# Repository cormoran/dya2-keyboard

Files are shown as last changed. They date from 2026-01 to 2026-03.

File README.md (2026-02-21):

# <picture><source srcset="docs/public/dya-dark.svg" media="(prefers-color-scheme: dark)"> DYA2 Split Keyboard

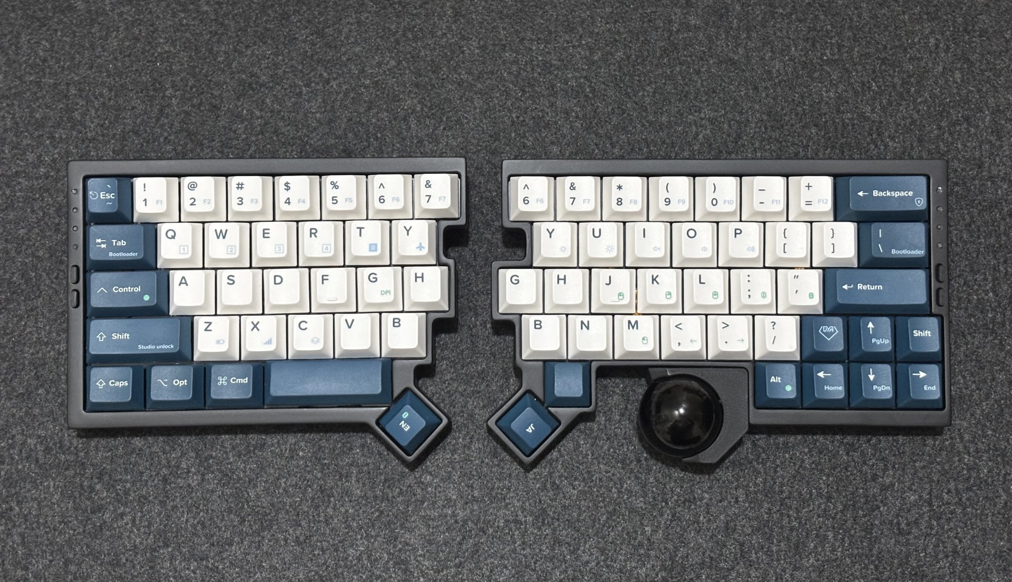
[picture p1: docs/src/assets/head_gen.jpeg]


Hardware designs are under preparation for publish...

## License

- DYA logo <picture><source srcset="docs/public/dya-dark.svg" media="(prefers-color-scheme: dark)">: All rights reserved.
- Other keyboard picture : CC BY
- Hardware
  - kicad library (./hardware/kicad_library/\*) and sch (\*.kicad_sch): MIT
  - PCB (\*.kicad_pcb): **CC BY-NC**
  - Case data (\*.stl): CC BY
- Documents
  - All pictures+ CC BY
  - Other source codes: MIT

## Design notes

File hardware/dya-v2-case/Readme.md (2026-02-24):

# DYA2 Keyboard Case Data

All files are available in [this Google Drive directory](https://drive.google.com/drive/folders/1ZEN23xsCUHo-18NyI8FSiMm8lmljceus?usp=drive_link).

## 2D DXF

3D data was designed based on below 2D DXF. But it can be different from 3D data, since some of the surfaces are edited directly in 3D model.

- [TopCase](https://drive.google.com/file/d/1yOBgUZQl2Zo97JnLZBKS5_XB2pb0bkpV/view?usp=drive_link)
- [BottomCase](https://drive.google.com/file/d/1IbZsgNPL-G4lhiw5IdBfzz8D3HgvFzjm/view?usp=drive_link)
- [TopPlate](https://drive.google.com/file/d/1yOBgUZQl2Zo97JnLZBKS5_XB2pb0bkpV/view?usp=drive_link)

## 3D Data

Link to the latest versions are summarized in below:

- For PLA with insert nut
  - [DYA2 v58.step](https://drive.google.com/file/d/1GUyOGR_NIzhSRBstqwC4YxvJoqwkRAov/view?usp=drive_link)
  - [DYA2-Trackball v4.stl](https://drive.google.com/file/d/1xNEte9bfMDOHjX-XjD9ouIbOX3-cyFVn/view?usp=drive_link)
    - stl because exporting to step file didn't work well :(
  - [XIAO-over v12 x 9.3mf](https://drive.google.com/file/d/1ttBiFGda33AoVqViXmSofXiBs5eIHgoY/view?usp=drive_link)
- For CNC
  - [DYA2 v37 Weight.step](https://drive.google.com/file/d/1O_AQXGu4fa-7VJVzOm7PxX8MRnGYcRql/view?usp=drive_link) - Tested with [JLCCNC](https://jlccnc.com/)

### 3mf for Bambu Studio

Below is an example setup for Bambu Studio for X1C.

- [TopCase and Weight](https://drive.google.com/file/d/1X5pBLtazw2v5_TMJEdkGAeLKjAuC2xHo/view?usp=drive_link)
- [BottomCase](https://drive.google.com/file/d/1tQdBppNNfY6DObMM-RVunVdRlT9PlLCL/view?usp=drive_link)]

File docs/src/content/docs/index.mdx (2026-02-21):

---
title: DYA2
description: 電池で動く、据え置き向け分割型トラックボール付きキーボード
template: splash
hero:
  title: |
    DYA2 Logo
    DYA2 Logo
    DYA2
  tagline: 電池で動く、据え置き向け分割型トラックボール付きキーボード
  image:
    file: ../../assets/head_gen.jpeg
    alt: DYA2 キーボード
  actions:
    - text: ビルドガイド
      link: /dya2-keyboard/build-guide/v1/
      icon: right-arrow
      variant: primary
    - text: 設計データ
      link: https://github.com/cormoran/dya2-keyboard
      icon: github
      variant: secondary
    - text: ビルドキットを購入
      link: https://cormoran707.booth.pm/items/7627440
      icon: information
      variant: minimal
    - text: DYA Studio で設定
      link: https://studio.dya.cormoran.works
      icon: right-arrow
      variant: secondary
---

import { Card, CardGrid } from "@astrojs/starlight/components";

## 特徴

<CardGrid>
<Card title="タッチセンサー搭載">
    キートップに触れると動作するタッチセンサーを搭載左右に４つずつ搭載できます。
    トラックボールのスクロールモード切り替えなどに便利です。
  </Card>
  <Card title="有線にも対応した無線左右分割キーボード">
    自由な手の位置でタイピングできます。

    安定性を重視する場面では、ケーブルを繋ぐだけで自動的に有線接続に切り替わります。

  </Card>
  <Card title="Web から設定を変更できる DYA Studio 対応">
    ファームウェアを書き換えることなく、キーマップの設定やトラックボールの調整、バッテリー履歴の確認がブラウザから行えます。
    <a href="https://studio.dya.cormoran.works">DYA Studio</a> は iOS からも利用できます。

  </Card>
  <Card title="電池駆動" >
    左右はそれぞれ単４電池１本ずつで動作します。

    リチウムポリマーバッテリーと比べて発火の心配が低く、安心して使用できます。

  </Card>
  <Card title="日本語配列にも対応">
    使い慣れた Row Staggered 配列の 60% キーボードです。

    同じハードウェアで英語配列と日本語配列の両方に対応しています。

    DYA Studio も日本語配列向けの表示に対応しています。

  </Card>
  <Card title="34mm トラックボール内蔵">
    マウスを持ち替えることなくカーソル操作が可能です。

    34mmの大きなトラックボールを搭載しているので、快適に操作できます。

  </Card>
  <Card title="自由なカスタマイズ">
    ZMKファームウェアを使っておりソースコードも公開しています。

    キーマップやマクロ、細かな振る舞いを自由にカスタマイズできます。

  </Card>
</CardGrid>

## 写真

## バージョン情報

ハードウェアに新しい機能が追加されたり、後方互換性の無い変更が行われた場合にメジャーバージョンアップします。

- **V1.1** (2026/02) - キーケット前の試作版

## サポート

- **販売・サポート**: [Booth](https://cormoran707.booth.pm)
- **技術情報・ソースコード**: [GitHub](https://github.com/cormoran/dya-dash-keyboard)
- **最新情報**: X [@cormoran707](https://twitter.com/cormoran707)

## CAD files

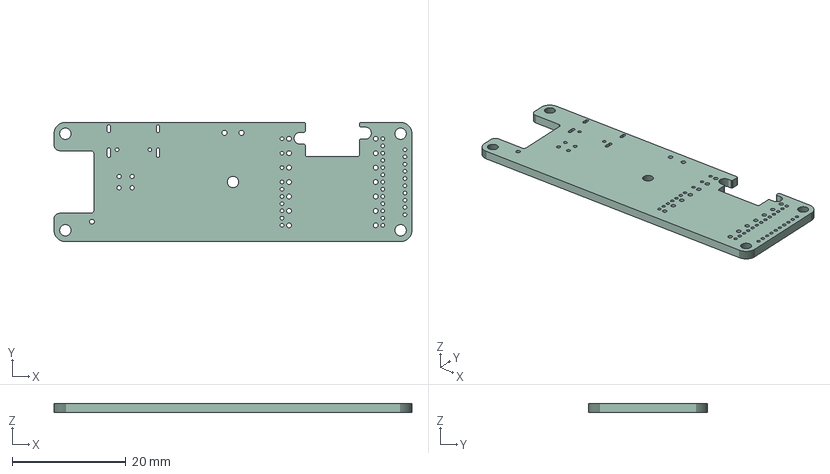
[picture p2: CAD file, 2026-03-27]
hardware/dya-v2/24pin-ffc-expander/mcu-xiao-nrf52840-plus.step
63.0 x 21.0 x 1.60 mm

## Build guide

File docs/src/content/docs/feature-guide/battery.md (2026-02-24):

---
title: バッテリー残量表示
sidebar:
  order: 5
---

電源を入れた際に左右のバッテリー残量が LED に表示されます。

バッテリー残量は、４つの LED x 3 色で 12 段階表示されます。

- ４つの LED: 下から25%ずつに対応
- 色: 残量が多い側から緑 → 黄 → 赤で変化

以下は DYA Dash での説明です。LED の向きが異なりますが基本的な読み方は同じです。

例えば下の図で、左手の緑緑緑は以下のように読みます。

- ４つ目が点灯していないので -25%で 75%以下
- ３つ目が緑なので、50%から 75%の間で残量が多い方（３分割した一番多い区間にある）

右手の緑緑黄状態は以下のように読みます

- ４つ目が点灯していないので -25%で 75%以下
- ３つ目が黄色なので、50%から 75%の間でちょうど真ん中あたり（３分割した真ん中の区間にある）

以下の画像は DYA Dash での例です。DYA2 では LED の向きが変わっていますが色は同じです

TODO: DYA2 で画像と説明を更新

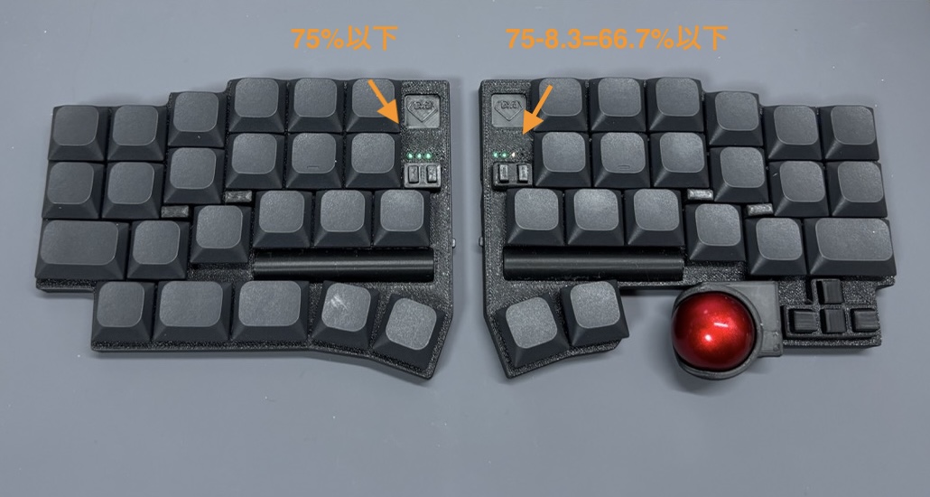
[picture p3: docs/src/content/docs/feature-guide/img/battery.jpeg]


:::note

残量表示はニッケル水素電池の電圧曲線に従って実装していますが、回路による電圧降下もあるため、実態に則しているかはまだあまり詳しく調べられていません。

全然違う気がした場合は教えてください。

:::

## 残量を確認する方法

電源を切らずに残量を確認するためには、 Config(下の赤いキー) + Z を押します。
しばらくの間 LED が電池残量を表示します。

その他、残量が少なくなったら定期的に LED をアラート点灯させる機能もついています。



## 電池持ちの分析

以下の記事で DYA Dash の回路でより詳しい Power profile 結果を解説しています。基本的には DYA2 でも同じような結果になります。

- [XIAO nrf52840 と ZMK を使ったキーボードのスリープ時消費電力](https://note.com/cormoran/n/n72a9d815ed55)
- [XIAO nrf52840 と ZMK を使ったトラックボールキーボード使用時の消費電力](https://note.com/cormoran/n/n7cd3f64d9a13)

## バッテリー残量履歴の確認

DYA Studio からバッテリー残量履歴の確認ができます。

:::tip[2026/02/25現在]
現在機能調整のため、公開しているファームウェアでは一時的に無効化しています。
:::

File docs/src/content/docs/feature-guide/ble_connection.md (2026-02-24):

---
title: 接続先の切り替え
sidebar:
  order: 3
---

接続先は Config レイヤーの `Q` `W` `E` `R` `T` で切り替えることができます。

また、現在の接続先は右手の４つのLEDから確認することができます。

- `Q`~`R`は無線接続0番から3番に対応
- LED は一番上が0番、一番下が３番に対応

### ペアリング/接続

Config レイヤーキー（下の図の赤いキー）を押しながら `Q`~`R` を押すと対応する接続先が選択され、右側の LED が以下のどれかの状態になります

- 黄色に点滅: ペアリング待機状態 PC から BLE 接続できます
- 赤く点滅: ペアリング済みの PC に接続待ち状態
- 青く点灯: 接続完了

### ペアリング解除

ペアリングを解除するためには、Config を押しながら `Q`~`R` を５秒以上押してください。

LED が黄色く点滅しペアリング待機状態に変わります。

### BLE/USB 切り替え

USB, BLE 両方に接続した状態で Config を押しながら以下の `OUT TOG` を押すと BLE/USB どちらが優先されるかが変わります。

USB が優先されている時、BLE接続先以外の３つのLEDが緑色に点灯します。



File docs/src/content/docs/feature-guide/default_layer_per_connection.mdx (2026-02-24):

---
title: 接続先ごとにキーマップを変える
description: DYA2 のデフォルトキーマップの解説
sidebar:
  order: 4
---

Windows PC と Mac や iPad など複数の OS とペアリングしている場合、OS ごとに必要なキーマップが違っていて困ります。

DYA2 には、接続先（BLE1, 2, 3, 4, USB）ごとにデフォルトレイヤーを切り替える機能が実装されています。

:::note

この機能は接続先の PC を識別してるわけではありません。例えば、USB を他の PC に差し替えるような場合は接続先ごとの切り替えはできません。

:::

Config(以下の赤いキー) + `df nxt`（左の設定ボタン上） を押すたびに、現在選択されている接続先のデフォルトレイヤーが 0 → 1 → 2 → 3 → 4 → 0 と切り替わり、レイヤーに対応する LED が点灯します。



### LED の意味

LED は左上から レイヤー0, 1, 2, 3 右上から 4, 5, 6, 7 に対応しています。

それぞれの LED は対応するレイヤーがアクティブなときに点灯します。接続先ごとに切り替えることができるのはレイヤー0~4の5つです。

- レイヤー 1~4 は接続先ごとに切り替えることができるレイヤーで、デフォルトでは以下のようにOSごとに割り当てる想定でキーマップとLEDの色を設定しています。 `df nxt` を押すたびに、LED が以下の順番で切り替わります。
  - 🔵 Layer1: Windows 空色
  - 🔴 Layer2: Mac 赤色
  - ⚪️ Layer3: iOS 白色
  - 🟠 Layer4: Linux オレンジ
- レイヤー0 はベースレイヤーで常にアクティブになるので、左の一つ目の LED は常に点灯します。Layer1~4 のどれも点灯していない状態は、接続先にレイヤー0が割り当てられている状態になります。
- レイヤー7 は Config レイヤーで、左手左下キーを押している間アクティブになるので、右の一番下の LED は赤いキーを押している間常に点灯します。
- レイヤー5,6 はマウスレイヤーで、トラックボール操作中の場合点灯します。

なお、Config + `C` キーで現在アクティブなレイヤーを確認することもできます。
例えば、Config + `C`を押した状態でトラックボールを動かすと右の上から３つ目のLEDが点灯するはずです。

なお、上の1~4のマッピングはあくまでおすすめとして設定してだけなので、レイヤーの使い方は自由です。

以下の動画は姉妹品の DYA Dash で接続先ごとにレイヤーが切り替わる様子を撮影したものです。DYA2 も同様の動作になります。

import { YouTube } from "astro-embed";

<YouTube id="PggxfXZUtnA" posterQuality="high" />

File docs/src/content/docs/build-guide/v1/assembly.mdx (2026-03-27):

---
title: 組み立て
description: 基板とケースを組み立てます
sidebar:
  order: 3
---

import { Image } from "astro:assets";
import { Steps } from "@astrojs/starlight/components";
import topPlateSeparated from "./img/assembly/1_1_top_plate_separated.jpeg";
import circuitBoardSeparated from "./img/assembly/1_2_circuit_board_separated.jpeg";

基板の切り離しから始めて、ケースへの取り付けと動作確認を行います。

:::caution[作業前の注意事項]

- **FFC ケーブル**: 乱雑に扱うと断線します。折り曲げる際は緩やかに行ってください
- **XIAO の取り付け**: コンスルーに無理な力を加えるとコンスルーが破損します
- **タッチセンサー端子**: 乱雑に扱うと断線するかもしれません
  :::

## 1. 基板の切り離し

回路基板とトッププレートを切り離します。ペンチやニッパーなどを使って基板を繋いでいるマウスビット部分を切断してください。
回路基板の方は手で折り曲げるだけで切断できます。トッププレートの薄い部分はそのまま折り曲げると割れる可能性があるので、プレート側をペンチで挟んで支えながら切断することをおすすめします。

バリが出ている場合はヤスリなどで整えます。

<div className="image-row">
  <Image src={topPlateSeparated} alt="トッププレートの切り離し後（左右）" />
  <Image
    src={circuitBoardSeparated}
    alt="回路基板の切り離し後（左右）"

/>

</div>

## 2. ボトムケースの組み立て

import bottomCaseOverview from "./img/assembly/2_bottom_case_overview.jpeg";

以下の部品と FFC ケーブルを用意します。

<div className="image-row">
  <Image src={bottomCaseOverview} alt="ボトムケースと部品一覧" />
  <div>
    <ul>
      <li>ネジパック A</li>
      <li>ボトムケース（左右）</li>
      <li>電池ケース x2</li>
      <li>制御基板 x2</li>
      <li>XIAO 固定用カバー x2</li>
      <li>電源スイッチカバー x2</li>
      <li>リセットボタン x1（右側用）</li>
      <li>XIAO nRF52840 Plus x2（ファームウェア書き込み済み）</li>
    </ul>
  </div>
</div>

### 2.1 電池ケースの取り付け

import batteryCase from "./img/assembly/2_1_battery_case.jpeg";
import batteryCaseScrewed from "./img/assembly/2_1_battery_case_screwed.jpeg";

電池ケースをボトムケースにはめ込み、左右ともに **M2 5mm ねじ（短い方）× 2** でねじ止めします。

M2 5mm ねじに適合するドライバーは１番サイズです。

<div className="image-row">
  <Image src={batteryCase} alt="電池ケースをボトムケースにはめ込む" />
  <Image src={batteryCaseScrewed} alt="電池ケースをねじ止めする" />
</div>

### 2.2 制御基板の組み立て

import xiaoCut from "./img/assembly/xiao_cut.jpeg";
import xiaoBoardAndCover from "./img/assembly/2_2_1_xiao_board_and_cover.jpeg";
import xiaoAttached from "./img/assembly/2_2_1_xiao_attached.jpeg";
import xiaoAttachedBoth from "./img/assembly/2_2_1_xiao_attached_both.jpeg";
import powerSw from "./img/assembly/2_2_2_power_sw.jpeg";
import powerSwSide from "./img/assembly/2_2_2_power_sw_side.jpeg";
import powerSwBoth from "./img/assembly/2_2_2_power_sw_both.jpeg";
import ffcCables from "./img/assembly/2_2_3_ffc_cables.jpeg";
import ffcRight from "./img/assembly/2_2_3_ffc_right.jpeg";
import ffcLeft from "./img/assembly/2_2_3_ffc_left.jpeg";

<Steps>

1. 制御基板を切り離す

   ２つの制御基板が繋がった状態で届いた場合は、基板を切り離します。手で折り曲げるだけで切り離せます。

1. 制御基板の XIAO のリセットスイッチにかぶる部分が切り欠きになっていることを確認する。
   もし画像の状態と違う場合はニッパーなどで出っ張りを切断し、以下の画像のようにしてください。これをしないと右側をボトムケースに取り付けるときにリセットスイッチが高確率で破損します。

   <div className="image-row">
     <Image src={xiaoCut} alt="制御基板の切り欠き" />
   </div>

1. **XIAO をコンスルーにはめ込む**

   XIAO の裏側が見えるように、USB コネクタが下側になる向きで制御基板のコンスルーの間にはめ込みます。

   コンスルーのピンは XIAO のピンの切り欠き部分に入るようになっています。

   <div className="image-row">
     <Image src={xiaoBoardAndCover} alt="制御基板とカバー" />
   </div>

1. **カバーを取り付ける**

   コンスルーのピンがカバーのスリットにピッタリと入っていることを確認しながら押し込みます。ずれたまま無理に押し込むとコンスルーが破損するので注意してください。
   この時点では押し込んでも浮き上がってきますが、問題ありません。次のステップでねじ止めして固定します。

   <div className="image-row">
     <Image src={xiaoAttached} alt="XIAO の取り付け" />
   </div>

1. **左右両方にカバーを取り付ける**

   <div className="image-row">
     <Image src={xiaoAttachedBoth} alt="左右のカバー取り付け完了" />
   </div>

1. **電源スイッチカバーを取り付ける**

   スイッチカバーには向きがあります。内部の切り欠きが片側に寄っているので、スペースが大きい方が基板側になるように取り付けてください。

   なお、スイッチカバーは強度と見た目でトレードオフがあるため、3Dプリントの印刷方向が異なる２種類が同梱されている場合があります。その場合はお好きな方をお使いください。もし取り付け時に破損した場合はもう一方をお使いください。

   <div className="image-row">
     <Image src={powerSw} alt="電源スイッチカバー（正面）" />
     <Image src={powerSwSide} alt="電源スイッチカバー（側面・向き確認）" />
   </div>

1. **左右両方に電源スイッチカバーを取り付ける**

   <div className="image-row">
     <Image src={powerSwBoth} alt="電源スイッチカバー左右取り付け完了" />
   </div>

1. **制御基板に FFC ケーブルを接続する**
   - **左側の基板**: 24pin のみ接続
   - **右側の基板**: 24pin と 6pin の両方を接続

   接続方法：コネクタの黒いロックを縦にして、FFC ケーブルの金属端子が基板側に来るように差し込み、ロックを横に倒して固定します。

   ２枚目の写真はロック解除の状態で、３枚目の写真はロックした状態です。

   <div className="image-row">
     <Image src={ffcCables} alt="FFC ケーブルの接続方法" />
     <Image src={ffcLeft} alt="左側：24pin のみ接続 ロック前" />
     <Image src={ffcRight} alt="右側：24pin + 6pin 接続　ロック後" />
   </div>

</Steps>

### 2.3 制御基板のボトムケースへの取り付け（右）

import resetButton from "./img/assembly/2_2_4_reset_button.jpeg";
import resetButtonAttaching from "./img/assembly/2_2_4_reset_attaching.jpeg";
import resetButtonAttached from "./img/assembly/2_2_4_reset_attached.jpeg";
import mountRightBattery from "./img/assembly/2_2_5_mount_right_battery.jpeg";
import mountRight from "./img/assembly/2_2_5_mount_right.jpeg";
import mountRightScrew from "./img/assembly/2_2_5_mount_right_screw.jpeg";
import mountRightScrew2 from "./img/assembly/2_2_5_mount_right_screw2.jpeg";

<Steps>

1.  **リセットボタンを取り付ける**

    右側のボトムケースに、太い側をボトムケースに差し込むようにリセットボタンを取り付けます。

    :::caution
    右のリセットボタンは現在試験的な機能扱いです。ボタンが非常に小さいため折れやすいです。

    ファームウェアの書き込みは専用のキーマップ(`&bootloader`)を使用することでリセットボタンなしでも行えるようになっています。
    :::

    <div className="image-row">
      <Image src={resetButton} alt="リセットボタン（取り付け前）" />
      <Image src={resetButtonAttaching} alt="リセットボタン（取り付け中）" />
      <Image src={resetButtonAttached} alt="リセットボタン（取り付け後）" />
    </div>

2.  **電池ケーブルを接続する**

    右側の制御基板に、電池ケースのケーブルを接続します。

    <div className="image-row">
      <Image src={mountRightBattery} alt="電池ケーブルの接続" />
    </div>

3.  **制御基板をボトムケースに入れる**

    USB 端子と電源スイッチが引っかからないよう、少し斜めから入れてください。力を入れなくても入るようになっています。

    :::caution
    無理に押し込むと電源スイッチやリセットボタンが破損します。
    :::

    <div className="image-row">
      <Image src={mountRight} alt="右側制御基板の挿入" />
    </div>

4.  **XIAO カバー部分をねじ止めする（長い方）**

    **M2 8mm ねじ（長い方）× 3** でねじ止めします。

    強く締めるとリセットボタンが押された状態になってしまう可能性があるので調整してください。

    <div className="image-row">
      <Image src={mountRightScrew} alt="右側 XIAO カバー部のねじ止め" />
    </div>

5.  **残りの穴をねじ止めする（短い方）**

    **M2 5mm ねじ（短い方）× 2** でねじ止めします。

    <div className="image-row">
      <Image src={mountRightScrew2} alt="右側基板の残りのねじ止め" />
    </div>

</Steps>

### 2.4 制御基板のボトムケースへの取り付け（左）

import mountLeft from "./img/assembly/2_2_6_mount_left.jpeg";
import mountLeftBattery from "./img/assembly/2_2_6_mount_left_battery.jpeg";
import mountingLeft from "./img/assembly/2_2_6_mounting_left.jpeg";
import mountingLeft2 from "./img/assembly/2_2_6_mounting_left2.jpeg";
import mountLeftScrew from "./img/assembly/2_2_6_mount_left_screw.jpeg";
import mountLeftScrew2 from "./img/assembly/2_2_6_mount_left_screw2.jpeg";
import mountLeftScrew3 from "./img/assembly/2_2_6_mount_left_screw3.jpeg";

:::note
左側の制御基板は、右側とは裏表が逆になります。
:::

<Steps>

1.  **電池ケーブルを接続する**

    左側の制御基板に、電池ケースのケーブルを接続します。

    <div className="image-row">
      <Image src={mountLeft} alt="左側制御基板（裏表確認）" />
      <Image src={mountLeftBattery} alt="電池ケーブルの接続" />
    </div>

2.  **制御基板をボトムケースに入れる**

    USB 端子と電源スイッチが引っかからないよう、少し斜めから入れてください。左側は右よりも余裕が少なくなっています。基板が押し返してきて入れづらいですが、注意深く入れてください。

    :::caution
    無理に押し込むと電源スイッチのノブ部分が折れるため注意深く入れてください。

    また、コンスルーのバネで基板が押し返されてくるので指で押さえたまま次のステップに進んでください。
    :::

    <div className="image-row">
      <Image src={mountingLeft} alt="左側制御基板の挿入（途中）" />
      <Image src={mountingLeft2} alt="左側制御基板の挿入（完了）" />
    </div>

3.  **中央の穴をねじ止めする（最初に止める）**

    **M2 8mm ねじ（長い方）× 1** にナイロンワッシャーを取り付けて**中央の穴をねじ止め**します。強く締めすぎるとケース裏側に盛り上がりができるので、しっかり固定しつつも締めすぎに注意してください。

    <div className="image-row">
      <Image src={mountLeftScrew} alt="左側中央穴のねじ止め" />
    </div>

4.  **XIAO カバー部分の残りをねじ止めする**

    **M2 8mm ねじ（長い方）× 2** とナイロンワッシャーでねじ止めします。

    <div className="image-row">
      <Image src={mountLeftScrew2} alt="左側 XIAO カバー部のねじ止め" />
    </div>

5.  **残りの穴をねじ止めする（短い方）**

    **M2 5mm ねじ（短い方）× 2** でねじ止めします。

    <div className="image-row">
      <Image src={mountLeftScrew3} alt="左側基板の残りのねじ止め" />
    </div>

</Steps>

## 3. エンブレムプレートの取り付け

import emblemPlateParts from "./img/assembly/3_emblem_plate.jpeg";
import emblemPlateAttached from "./img/assembly/3_emblem_plate_attached.jpeg";
import emblemPlateBottom1 from "./img/assembly/3_emblem_plate_bottom1.jpeg";
import emblemPlateBottom2 from "./img/assembly/3_emblem_plate_bottom2.jpeg";
import emblemPlateBottom3 from "./img/assembly/3_emblem_plate_bottom3.jpeg";

ネジパック B、ボトムエンブレム x2、ボトムケースを用意します。
画像では右側に特注の真鍮製プレートを使用しています（詳細は[追加のカスタマイズ](/dya2-keyboard/build-guide/v1/extension)を参照）。

<div className="image-row">
  <Image src={emblemPlateParts} alt="エンブレムプレートの取り付け部品" />
</div>

エンブレムプレートをはめ込み、**M2 4mm ねじ（黒色）× 4** でねじ止めします。ねじが短いのでねじ穴が潰れやすいです。ガタつかない程度に固定できれば問題ありません。締めすぎに注意してください。

M2 4mm ねじに適合するドライバーは０番サイズです。

<div className="image-row">
  <Image src={emblemPlateAttached} alt="エンブレムプレート取り付け後" />
</div>

取り付け後のボトムケースはこのような状態になります。

<div className="image-row">
  <Image src={emblemPlateBottom1} alt="エンブレムプレート取り付け後の底面" />
</div>

参考：JLCPCB で真鍮プレートを鏡面加工したものと通常仕上げの比較です。

<div className="image-row">
  <Image
    src={emblemPlateBottom2}
    alt="真鍮プレート（鏡面加工あり）"/>

<Image src={emblemPlateBottom3} alt="真鍮プレート（通常仕上げ）" />

</div>

## 4. トラックボール基板の取り付け

import trackballParts from "./img/assembly/4_trackball_parts.jpeg";
import trackballLens from "./img/assembly/4_trackball_lens.jpeg";
import trackballLens2 from "./img/assembly/4_trackball_lens2.jpeg";
import trackballFfc from "./img/assembly/4_trackball_ffc.jpeg";
import trackballCase from "./img/assembly/4_trackball_case.jpeg";
import trackballCase2 from "./img/assembly/4_trackball_case2.jpeg";
import trackballCase3 from "./img/assembly/4_trackball_case3.jpeg";
import trackballCase4 from "./img/assembly/4_trackball_case4.jpeg";
import trackballMounted from "./img/assembly/4_trackball_mounted.jpeg";
import trackballScrew from "./img/assembly/4_trackball_screw.jpeg";
import trackballScrew2 from "./img/assembly/4_trackball_screw2.jpeg";
import trackballFinal from "./img/assembly/4_trackball_final.jpeg";

ネジパック B の残りと以下の部品を用意します。

<div className="image-row">
  <Image src={trackballParts} alt="トラックボール関連部品" />
</div>

<Steps>

1.  **保護シートを剥がす**

    トラックボールセンサーについている茶色の保護シートを剥がします。剥がすとセンサーの穴が露出します（上の画像は剥がした状態）。

2.  **レンズを取り付ける**

    レンズの突起がセンサーの穴に入るように取り付けます。突起は裏側に突き出ます。はんだごてがある場合は突起部分に熱を加えて溶かして固定します。ニッパーで切断するだけでも問題ありません。

    <div className="image-row">
      <Image src={trackballLens} alt="レンズの取り付け（前）" />
      <Image src={trackballLens2} alt="レンズの取り付け（後）" />
    </div>

3.  **6pin FFC ケーブルをセンサー基板に接続する**

    コネクタの黒いロックを縦にして、FFC ケーブルの金属端子が基板側に来るようにして差し込み、ロックを横に倒して固定します。

    <div className="image-row">
      <Image src={trackballFfc} alt="トラックボールセンサーへの FFC 接続" />
    </div>

4.  **センサー基板をトラックボールケースに収める**

    FFC ケーブルをうまく折り曲げて端子に負荷がかからないように差し込みます。FFC ケーブルを強く曲げると断線するので注意してください。

    <div className="image-row">
      <Image src={trackballCase} alt="センサー基板の挿入（途中 1）" />
      <Image src={trackballCase2} alt="センサー基板の挿入（途中 2）" />
      <Image src={trackballCase3} alt="センサー基板の挿入（途中 3）" />
    </div>

5.  **カバーを取り付ける**

    奥まで差し込んだらカバーを取り付けます。

    <div className="image-row">
      <Image src={trackballCase4} alt="トラックボールケースのカバー取り付け" />
    </div>

6.  **ボトムケースに乗せて裏返す**

    <div className="image-row">
      <Image src={trackballMounted} alt="トラックボールをボトムケースに設置" />
    </div>

7.  **ねじ止めする**

    **M2 4mm ねじ（黒色）× 3** で軽くねじ止めします。後でトラックボール位置を調整できるので、この時点では軽く止める程度で大丈夫です。

    <div className="image-row">
      <Image src={trackballScrew} alt="トラックボールのねじ止め" />
      <Image src={trackballScrew2} alt="トラックボールのねじ止め（別角度）" />
    </div>

8.  **FFC ケーブルの位置を調整する**

    <div className="image-row">
      <Image src={trackballFinal} alt="FFC ケーブル位置調整後" />
    </div>

</Steps>

## 5. キースイッチ基板の組み立て

import keyswitchOverview from "./img/assembly/5_keyswitch.jpeg";
import keyswitchTadpole from "./img/assembly/5_1_tadpole1.jpeg";
import keyswitchTadpole2 from "./img/assembly/5_1_tadpole2.jpeg";
import keyswitchSettingSwitch from "./img/assembly/5_2_setting_switch.jpeg";
import keyswitchSettingSwitch2 from "./img/assembly/5_2_setting_switch2.jpeg";
import keyswitchSettingSwitchBoth from "./img/assembly/5_2_setting_switch_both.jpeg";
import keyswitchStabilizer from "./img/assembly/5_3_stabilizer_en.jpeg";
import keyswitchPre from "./img/assembly/5_4_keyswitch_pre.jpeg";
import keyswitchPre2 from "./img/assembly/5_4_keyswitch_pre2.jpeg";
import keyswitchPreBoth from "./img/assembly/5_4_keyswitch_pre_both.jpeg";
import touchSensor from "./img/assembly/5_5_touch_sensor.jpeg";
import touchSensorTape from "./img/assembly/5_5_touch_sensor_tape.jpeg";
import touchSensorTape2 from "./img/assembly/5_5_touch_sensor_tape2.jpeg";
import touchSensorScrew from "./img/assembly/5_5_touch_sensor_screw.jpeg";
import touchSensorAll from "./img/assembly/5_5_touch_sensor_all.jpeg";
import keyswitchClick from "./img/assembly/5_6_keyswitch_click.jpeg";
import keyswitchClick2 from "./img/assembly/5_6_keyswitch_click2.jpeg";
import keyswitchLeft from "./img/assembly/5_6_keyswitch_left1.jpeg";
import keyswitchLeft2 from "./img/assembly/5_6_keyswitch_left2.jpeg";
import keyswitchTouchSensor from "./img/assembly/5_6_keyswitch_touchsensor.jpeg";
import keyswitchTouchSensor2 from "./img/assembly/5_6_keyswitch_touchsensor2.jpeg";
import keyswitchFinal from "./img/assembly/5_final.jpeg";

以下の部品を用意します。

<div className="image-row">
  <Image src={keyswitchOverview} alt="キースイッチ基板組み立ての部品一覧" />
  <div>
    <ul>
      <li>スタビライザー</li>
      <li>キースイッチ</li>
      <li>Tadpole ピン</li>
      <li>設定スイッチ x4（左右２つずつ）</li>
      <li>ねじパック C</li>
      <li>タッチセンサー</li>
      <li>トッププレート</li>
      <li>キースイッチ基板</li>
    </ul>
  </div>
</div>

### 5.1 Tadpole ピンの取り付け

Tadpole ピンをトッププレートの裏側から差し込みます。

<div className="image-row">
  <Image src={keyswitchTadpole} alt="Tadpole ピンの取り付け（右側）" />
  <Image src={keyswitchTadpole2} alt="Tadpole ピンの取り付け（左側・裏返し）" />
</div>

### 5.2 設定スイッチの取り付け

設定スイッチを左右２つずつキースイッチ基板に差し込みます。はんだ付けしない場合はピンのバネの力で導通します。はんだごてをお持ちの場合ははんだ付けを推奨します。

<div className="image-row">
  <Image src={keyswitchSettingSwitch} alt="設定スイッチの取り付け" />
  <Image src={keyswitchSettingSwitch2} alt="設定スイッチの取り付け（別角度）" />
  <Image src={keyswitchSettingSwitchBoth} alt="設定スイッチ左右取り付け完了" />
</div>

### 5.3 スタビライザーの取り付け

キースイッチ基板にスタビライザーを取り付けます。

- **英語配列**の配置は下の画像のとおりです
- **日本語配列**の場合：右上と左内側のスタビライザーは不要、右中央のスタビライザーはエンターキーに合わせた縦向きに変更してください

スタビライザーにルブを塗る場合は取り付ける前に塗ってください。

<div className="image-row">
  <Image src={keyswitchStabilizer} alt="スタビライザーの取り付け（英語配列）" />
  <div style="align-self: center; text-align: center;">
    日本語配列の写真: 準備中
  </div>
</div>

### 5.4 キースイッチの仮止め

トッププレートの４隅にキースイッチをはめ込み、キースイッチ基板に差し込みます。

:::caution
次の手順でタッチセンサーを取り付けるため、**親指エリアのキースイッチは今はまだ取り付けないでください**

下の画像の左では誤って取り付けてしまっています。一つ上か左の場所に取り付けてください。
:::

<div className="image-row">
  <Image src={keyswitchPre} alt="キースイッチの仮止め（片側）" />
  <Image src={keyswitchPre2} alt="キースイッチの仮止め（別角度）" />
  <Image src={keyswitchPreBoth} alt="キースイッチの仮止め（左右）" />
</div>

### 5.5 タッチセンサーの取り付け（スキップ可）

タッチセンサーはキーキャップの裏側に貼り付けて、回路基板にねじ止めします。**端子は繊細なので丁寧に扱ってください**。
対応しているキーは以下の画像+`V`です（**`F` と `V` はどちらか片方のみ**）。

タッチセンサーは後から取り付けすることも可能です。最大８つ設置できますが、まずは使い道が明確なキーだけ取り付けることをおすすめします。
`'` はトラックボールをスクロールモードに切り替えるのにおすすめです。

<div className="image-row">
  <Image src={touchSensor} alt="タッチセンサー対応キーの位置" />
</div>

<Steps>

1.  **タッチセンサーをキーキャップに貼り付ける**

    両面テープを画像のように貼り付けて４辺を折り曲げ、キーキャップ内側に貼り付けます。表裏はどちらでも良いですが、金属面をキーキャップ側（指に近い側）にすると良いかもしれません。ねじ止め部分がキーキャップの上側に来る向きにしてください。

    <div className="image-row">
      <Image src={touchSensorTape} alt="タッチセンサーへの両面テープ貼り付け" />
      <Image
        src={touchSensorTape2}
        alt="タッチセンサーをキーキャップに貼り付け"
      />
    </div>

2.  **タッチセンサーをねじ止めする**

    ネジパック C の **M2 3mm ねじ × 1（センサーごと）** でねじ止めします。導通するようにしっかりとねじ止めしてください。

    <div className="image-row">
      <Image src={touchSensorScrew} alt="タッチセンサーのねじ止め" />
      <Image src={touchSensorAll} alt="タッチセンサー全体の取り付け完了" />
    </div>

</Steps>

### 5.6 残りのキースイッチとキーキャップの取り付け

残りすべてのキースイッチとキーキャップを取り付けます。

<div className="image-row">
  <Image src={keyswitchLeft} alt="キースイッチ取り付け（左側途中）" />
  <Image src={keyswitchFinal} alt="キースイッチ全て取り付け完了" />
</div>

タッチセンサー付きのキーキャップは、接続部がスイッチの上側に挟み込まれるようになります。

<div className="image-row">
  <Image
    src={keyswitchTouchSensor}
    alt="タッチセンサー付きキーキャップの取り付け"
  />
  <Image
    src={keyswitchTouchSensor2}
    alt="タッチセンサー付きキーキャップの取り付け（別角度）"
  />
  <Image
    src={keyswitchLeft2}
    alt="タッチセンサー付きキーキャップをスイッチに装着"
  />
</div>

マウスの左クリックとして使うキー（`M` が推奨）にはタクタイルスピードスイッチがおすすめです。

<div className="image-row">
  <Image src={keyswitchClick} alt="左クリック用スイッチの取り付け" />
  <Image src={keyswitchClick2} alt="左クリック用スイッチの取り付け（別角度）" />
</div>

## 6. トップケースの組み立て

import topCaseOverview from "./img/assembly/6_topcase.jpeg";
import topCaseLeftSettingSwitch from "./img/assembly/6_1_left_setting_switch.jpeg";
import topCaseLeftCircuit from "./img/assembly/6_1_left_circuit.jpeg";
import topCaseLeftCircuit2 from "./img/assembly/6_1_left_circuit2.jpeg";
import topCaseLeftFfc from "./img/assembly/6_1_left_ffc.jpeg";
import topCaseLeftFfc2 from "./img/assembly/6_1_left_ffc2.jpeg";
import topCaseLeftMerge from "./img/assembly/6_1_left_merge.jpeg";
import topCaseRightCircuit from "./img/assembly/6_2_right_circuit.jpeg";
import topCaseRightFfc from "./img/assembly/6_2_right_ffc.jpeg";
import topCaseRightMerge from "./img/assembly/6_2_right_merge.jpeg";
import topCaseScrew from "./img/assembly/6_3_screw.jpeg";
import topCaseScrew2 from "./img/assembly/6_3_screw2.jpeg";
import bottomPad from "./img/assembly/6_4_pad.jpeg";
import batteryCover from "./img/assembly/6_5_battery_cover.jpeg";
import batteryCover2 from "./img/assembly/6_5_battery_cover2.jpeg";
import batteryCover3 from "./img/assembly/6_5_battery_cover3.jpeg";

ネジパック B の残り、ゴム足、ボトムケースと以下の部品を用意します。

<div className="image-row">
  <Image src={topCaseOverview} alt="トップケース組み立ての部品一覧" />
</div>

### 6.1 左側のトップケースの組み立て

<Steps>

1.  **設定スイッチを取り付ける**

    左側のトップケースを裏返して設定スイッチを取り付けます。出っ張りが内側になるようにしてください（正しい向きにしか入りません）。

    <div className="image-row">
      <Image
        src={topCaseLeftSettingSwitch}
        alt="左側トップケースに設定スイッチを取り付け"
      />
    </div>

2.  **回路基板を入れる**

    真っ直ぐ入れると LED 部分が干渉するので、少し斜めから入れてください。

    <div className="image-row">
      <Image src={topCaseLeftCircuit} alt="左側トップケースへの回路基板挿入" />
    </div>

3.  **Tadpole ピンをはめ込む**

    Tadpole ピンをトップケースの穴にしっかりと合わせて奥まで押し込みます。

    <div className="image-row">
      <Image
        src={topCaseLeftCircuit2}
        alt="Tadpole ピンをトップケース穴にはめ込む"
      />
    </div>

4.  **FFC ケーブルを接続する**

    ボトムケースから出ている 24pin FFC ケーブルをトップケースの回路基板に接続します。上下を合わせた状態をイメージして、ケーブルを緩やかに折り曲げて接続してください。**FFC ケーブルは強く曲げると断線します。一度曲げたら戻さないようにしてください。**

    FFC ケーブルは青い樹脂部分が見える側を上に、金属端子が基板側に来るように差し込み、ロックを横に倒して固定します。

    <div className="image-row">
      <Image src={topCaseLeftFfc} alt="左側 FFC ケーブルの折り曲げ方向" />
      <Image src={topCaseLeftFfc2} alt="左側 FFC ケーブルの接続完了" />
    </div>

5.  **ボトムケースと合体させる**

    FFC ケーブルがうまく収まるように調整しながら、トップケースの回路基板をボトムケースの基板に重ねます。Tadpole ピンが外れやすいので、下の画像のように上下逆の状態で取り付けると安定します。

    <div className="image-row">
      <Image
        src={topCaseLeftMerge}
        alt="左側トップケースとボトムケースの合体"
      />
    </div>

</Steps>

### 6.2 右側のトップケースの組み立て

<Steps>

1.  **設定スイッチを取り付ける**

    右側のトップケースを裏返して、設定スイッチを取り付けます。

2.  **回路基板を入れる**

    こちらも LED 部分が干渉するので少し斜めから入れます。入れたら Tadpole ピンをトップケースの穴にしっかりと合わせて奥まで押し込みます。

    <div className="image-row">
      <Image src={topCaseRightCircuit} alt="右側トップケースへの回路基板挿入" />
    </div>

3.  **FFC ケーブルを接続する**

    ボトムケースから出ている 24pin FFC ケーブルを接続します。右側はボトムケースの基板が左とは逆向きになっているため、FFC ケーブルも左側とは逆向きになっており、折り曲げ方を変える必要があります。以下の写真を参考にしてください。**一度曲げたら戻さないようにしてください。**

    <div className="image-row">
      <Image src={topCaseRightFfc} alt="右側 FFC ケーブルの接続" />
    </div>

4.  **ボトムケースと合体させる**

    FFC ケーブルがうまく収まるように調整しながら重ねてください。

    <div className="image-row">
      <Image
        src={topCaseRightMerge}
        alt="右側トップケースとボトムケースの合体"
      />
    </div>

</Steps>

### 6.3 動作確認

ねじ止めする前に動作を確認します。

:::danger
PCとの接続は左右外側のUSB端子を使用してください。左右内側のUSB端子は左右の基板を接続するためのもので、PCとの接続には使用できません。PCが故障する可能性があります。

また、左右をUSB接続した状態で左右両方をPCと接続しないでください。USB電源の逆流対策がされていないため、PCやPCのUSB端子が故障する可能性があります。
:::

<Steps>

1. 有線接続での確認

   右の外側のUSB 端子をPCと接続、左右の内側のUSB端子を互いに接続して、キー入力とトラックボールの動作を確認します。

   なお、左の外側のUSB 端子はファームウェア書き込みのためだけに使用されます。左をPCと接続してもキーボードとしては動作しません。

1. 左右無線での確認（組み立て後でもOK）

   左右の内側のUSB端子を外して左に電池を入れます。左の電源をオン（スイッチを内側にスライド）にして、キー入力とトラックボールの動作を確認します。

1. すべて無線での確認（組み立て後でもOK）

   右側にも電池を入れて、右の電源もオンにします（スイッチを内側にスライド）。

   右のLEDが黄色に点滅している状態でPCやスマートフォンとペアリングしてください。ペアリング方法の詳細は[使い方ガイド](/dya2-keyboard/usage-guide)にも記載しています。

1. すべてのキーが安定して入力できること、トラックボールが正常に動作することを確認してください。

</Steps>

もし左右で逆のファームウェアを書き込んでしまっていた場合は再度正しいファームウェアを書き込んでください。

右側はケース裏のリセットボタンを素早く２回押すと書き込みモードに入ります。

左側は上下のケースを開けて、爪楊枝の腹（尖っていない方）など突起のあるものでリセットボタンを押す必要があります。

:::tip[一部のキーが反応しない/反応が悪い場合]
以下のような点を確認してみてください。もしキーソケットと基板のはんだが外れている場合は、はんだ付けをしていただけると非常にありがたいです。
難しい場合は購入されたプラットフォームのメッセージ機能でご相談ください。

- キースイッチのピンが曲がらずしっかりソケットに差し込まれているか
- キーソケットと基板のはんだが外れてソケットが浮いていないか
- FFC ケーブルが真っ直ぐに差し込まれてソケットがロックされているか
- XIAO の端子とコンスルール基板の接点がしっかり接触しているか
  :::

### 6.4 トップケースとボトムケースのねじ止め

下側5箇所は **M2 8mm ねじ（長い方）**、上側4箇所は **M2 5mm ねじ（短い方）** でねじ止めします。

<div className="image-row">
  <Image src={topCaseScrew} alt="ねじ止め位置（下側）" />
  <Image src={topCaseScrew2} alt="ねじ止め位置（上側）" />
</div>

### 6.5 ゴム足の取り付け

裏側の８箇所にゴム足を貼り付けます。

<div className="image-row">
  <Image src={bottomPad} alt="底面のゴム足の取り付け位置" />
</div>

### 6.6 電池カバーの取り付け

電池カバーは裏側から差し込むように取り付けます。カバーは最初は少し硬いですが、何度か取り付けるうちに柔らかくなってきます。

カバーは取り付けるとロックされたような状態になっており、カバーの上部を押さえながら指の腹で少しスライドすると外れる設計になっています。爪を使って無理に引っ張ると爪が割れる可能性があるのでご注意ください。

<div className="image-row">
  <Image src={batteryCover} alt="電池カバーの取り付け（差し込み）" />
  <Image src={batteryCover2} alt="電池カバーの取り付け（ロック）" />
  <Image src={batteryCover3} alt="電池カバーの取り付け完了" />
</div>

## 完成！

import topCaseFinal from "./img/assembly/6_final.jpeg";

<div className="image-row">
  <Image src={topCaseFinal} alt="DYA2 完成！" />
</div>

お疲れさまでした！続いて使い方ガイドをご覧ください。

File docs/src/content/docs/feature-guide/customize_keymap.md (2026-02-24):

---
title: キーマップのカスタマイズ
description: DYA2 のキーマップカスタマイズ方法の解説
sidebar:
  order: 2
---

DYA2 のキーマップを変更する方法を解説したページです。
自由度と難易度の違う３つの方法があります。

1. **DYA Studio**: 最も簡単にさまざまな設定ができます。一部複雑なカスタマイズはできませんが今後機能を追加予定です。
   - **ZMK Studio**: ZMK 公式のキーマップカスタマイズツールです。最新機能が使える可能性がありますが、基本的には DYA Studio で同等以上の機能が提供されています。
2. **keymap editor**: Github レポジトリを作る必要がありますが、プログラミングなしで ZMK Studio よりも複雑なカスタマイズができます。
3. **プログラミング**: プログラミングの知識が必要ですが自由自在にカスタマイズができます。

## 1. DYA Studio を使ったカスタマイズ

ZMK Studio と同等のキーマッピング変更に加えて、トラックボールの調整などがファームウェア書き換えなしに行えます。

https://studio.dya.cormoran.works/ からアクセスできます。

### USB 接続でアクセスする方法

WebSerial に対応したブラウザで利用できます。モバイルOSでは利用できません。

1. PC とキーボード右手の外側の USB ポートを接続
2. https://studio.dya.cormoran.works/ にアクセスして USB マークの接続ボタンを選択
3. DYA2 を選択して接続
4. Fn+Caps (Fn:右下の一つ上, Caps: 左下)で `&studio unlock` を実行

※2024/02/24 現在一部の機能は左右を有線接続した状態では正常に動作しません。左右は無線接続にした状態でご利用ください。必要な実装していないだけなので今後対応予定です。

### 無線接続でアクセスする方法

Web Bluetooth に対応したブラウザで利用できます。iOS の場合は Bluefy というブラウザアプリから接続できます。Android は未検証です。

1. キーボードの USB ケーブルを外すか、無線接続優先モードに変更
2. Fn+Caps (Fn:右下の一つ上, Caps: 左下)で `&studio unlock` を実行
   - これを先にやらないと次のステップでデバイスが見つかりません
3. https://studio.dya.cormoran.works/ にアクセスして BLE マークの接続ボタンを選択
4. DYA2 を選択して接続
   - iOS の場合は現在周りにあるすべての BLE デバイスが表示されます。たくさんの無線機器に囲まれて暮らしている方はがんばって DYA2 を探してください。（今後できれば改善予定）

### 参考: ZMK Studio を使ったカスタマイズ

基本的には DYA Studio と同じように利用できます。以下の２種類の方法があります。

- ブラウザ上で動く公式サイト https://zmk.studio/ (USB 接続時のみ対応)
- PC アプリ https://zmk.studio/download (無線接続時も対応)

## 2. keymap editor を使ったカスタマイズ

ファームウェアのソースコードを自動で書き換えてくれるノーコードツール https://nickcoutsos.github.io/keymap-editor/ を使ったカスタマイズ方法です。
ZMK Studio ではできないマクロなどの高度なカスタマイズができます。

:::note[注意]
以下の内容は DYA2 のレポジトリではまだ検証できていません。
:::

### 設定レポジトリを Github に準備する

1. https://github.com/ のアカウントを作ります。
2. https://github.com/cormoran/zmk-keyboard-dya2 をテンプレートとして設定レポジトリを作ります。
   以下の画像は DYA Dash の使い回しです。

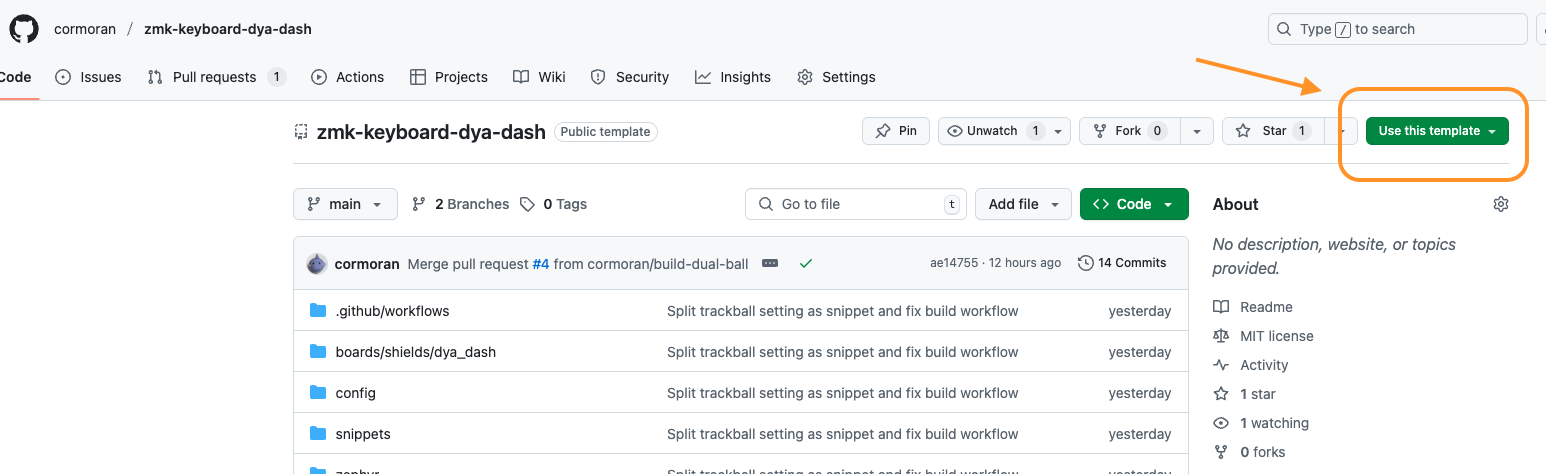
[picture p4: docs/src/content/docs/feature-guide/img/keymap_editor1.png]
   

3. 自動的にファームウェアのビルドが始まることを確認します。
   - 作成されたレポジトリの "Actions" タブをクリックすると "Initial commit" という workflow が動いていると思います。
   - ビルドが終わるとその workflow の Summary ページの Artifacts に zip 圧縮されたファームウェア一式をダウンロードできるリンクが出現します。

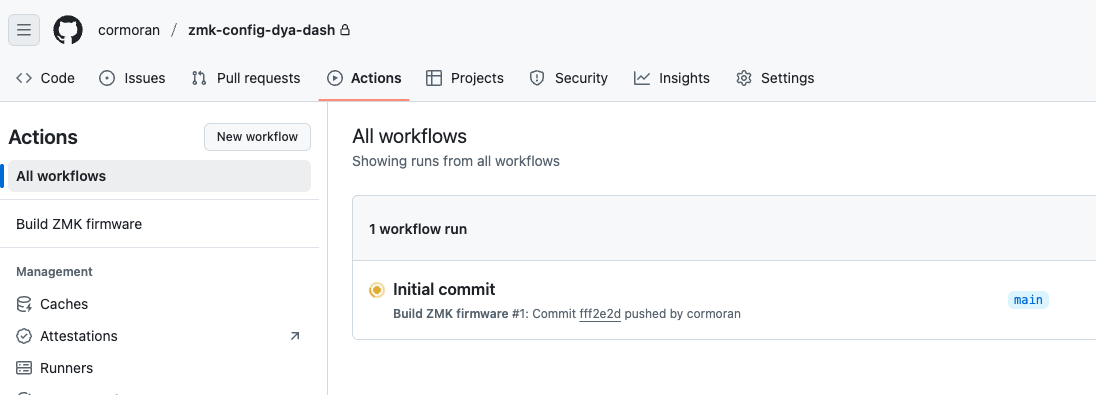
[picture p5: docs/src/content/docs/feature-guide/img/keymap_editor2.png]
   
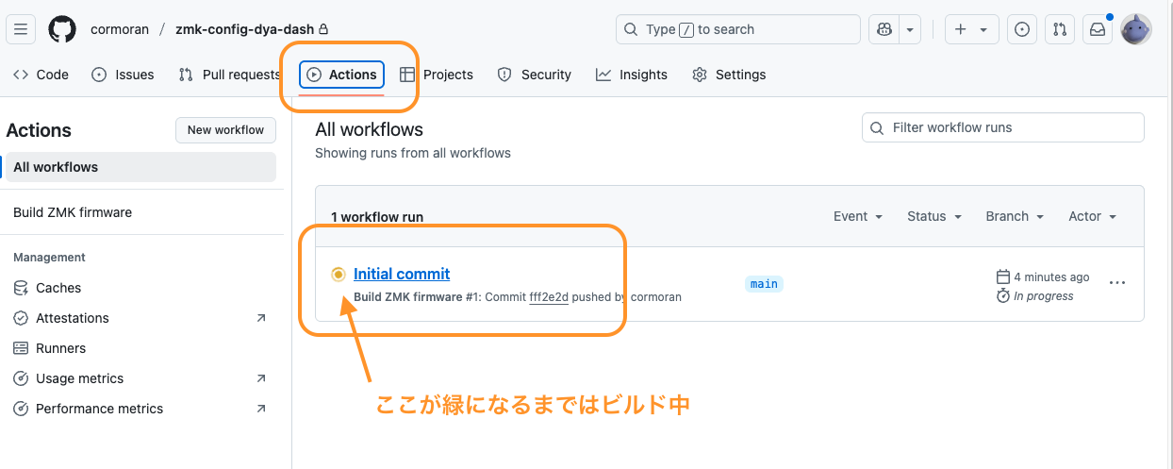
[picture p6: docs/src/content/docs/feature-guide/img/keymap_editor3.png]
   
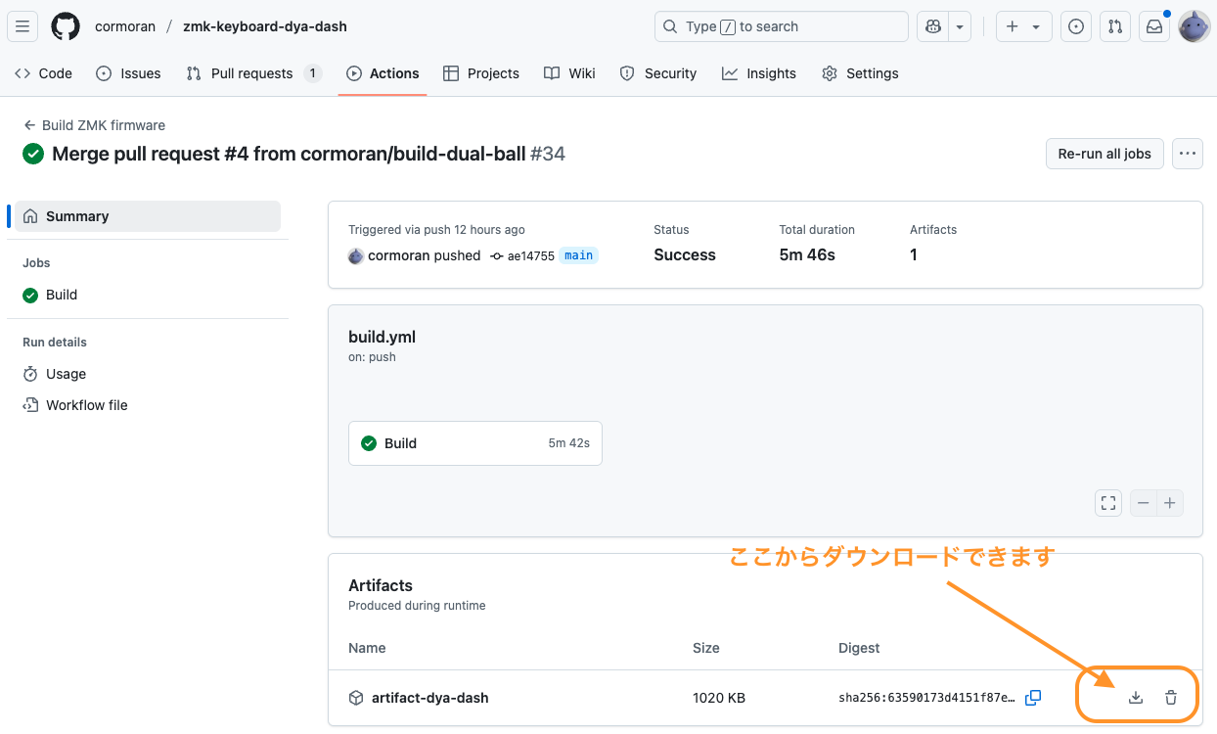
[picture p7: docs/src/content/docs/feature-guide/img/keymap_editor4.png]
   

### keymap editor で設定を編集

1.  https://nickcoutsos.github.io/keymap-editor/ を開いて、github アカウントと連携します。

    | GitHub を選択                 | Login with GitHub             |
    | ----------------------------- | ----------------------------- |
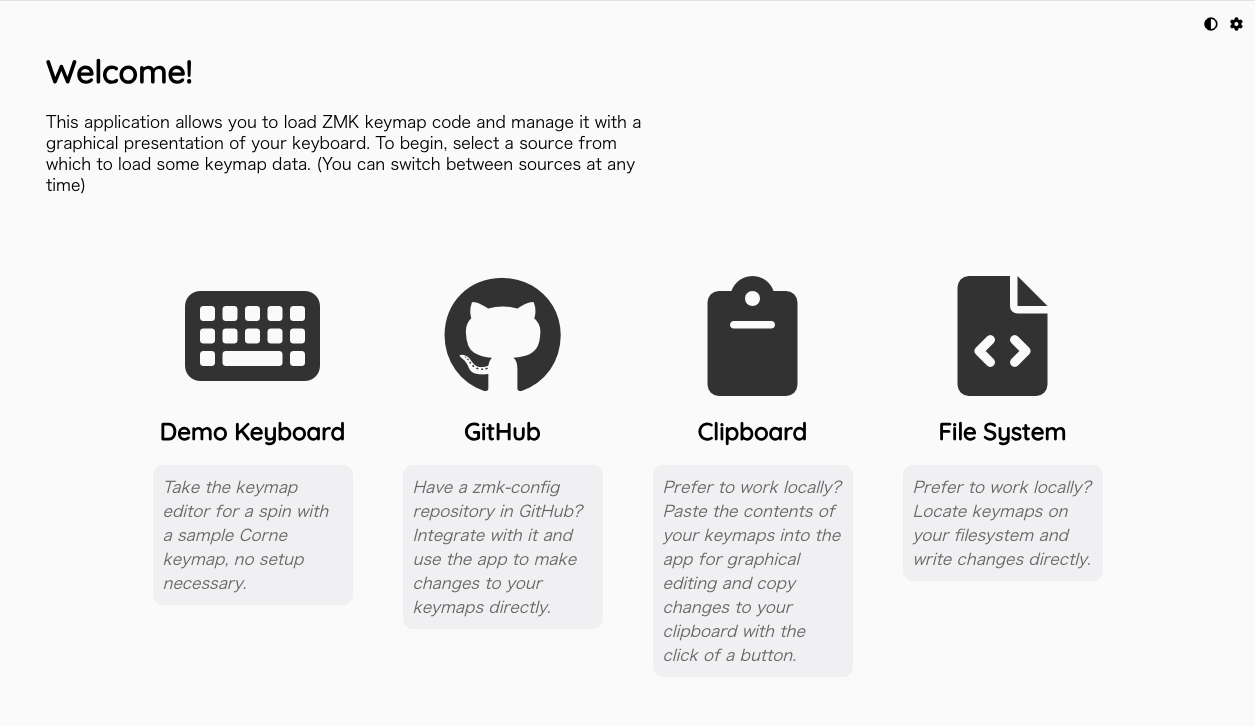
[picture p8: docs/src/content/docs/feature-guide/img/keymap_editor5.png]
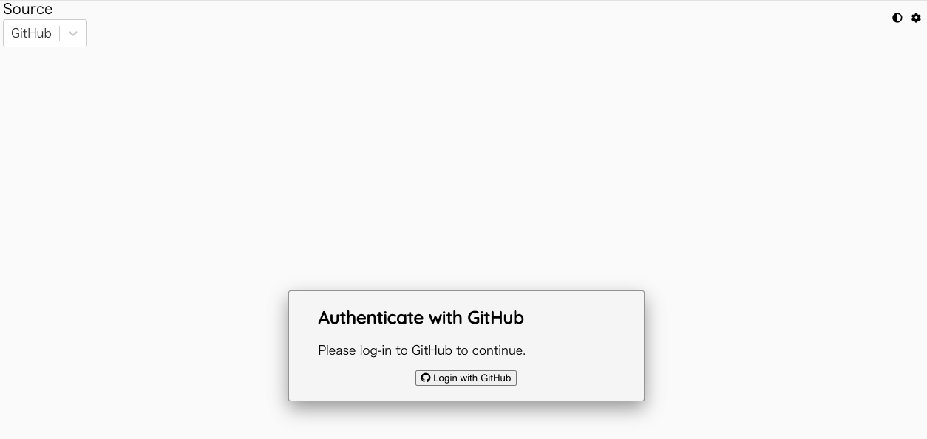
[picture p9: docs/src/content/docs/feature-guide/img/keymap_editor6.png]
    |  |  |

    | Add Repository                | All repository か、上で作成したレポジトリを個別に選ぶ |
    | ----------------------------- | ----------------------------------------------------- |
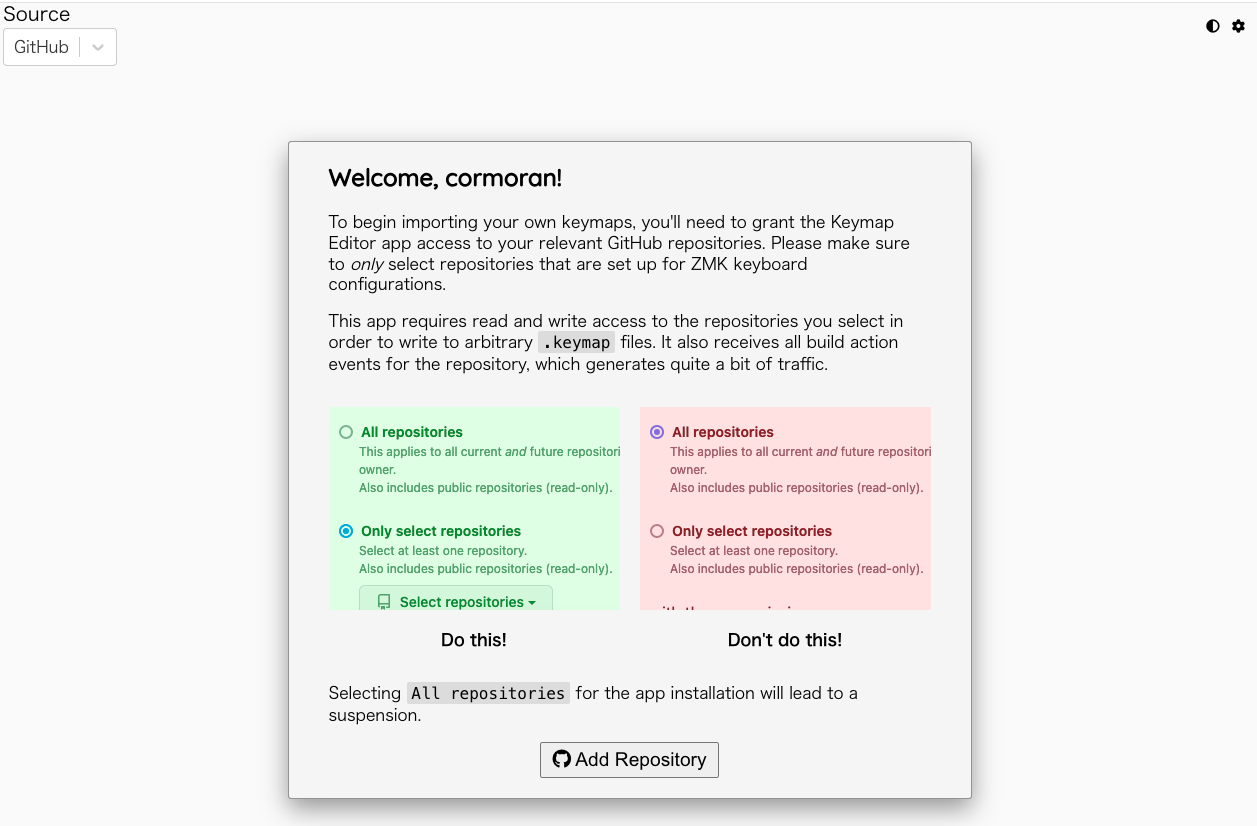
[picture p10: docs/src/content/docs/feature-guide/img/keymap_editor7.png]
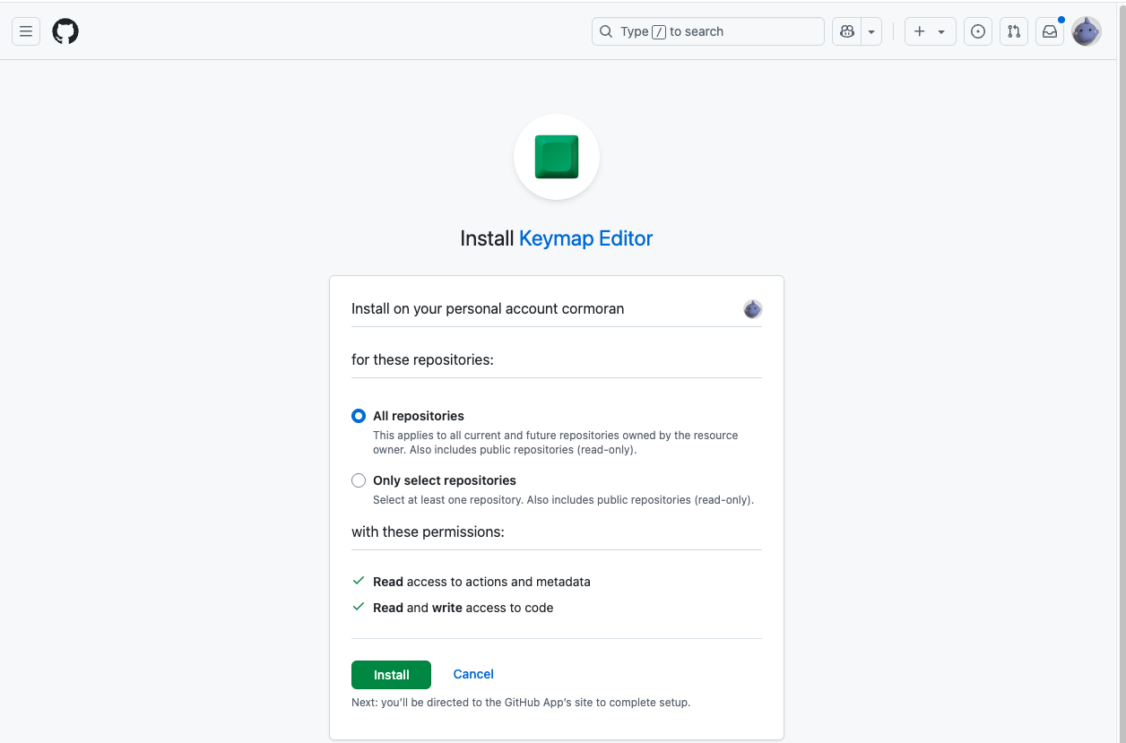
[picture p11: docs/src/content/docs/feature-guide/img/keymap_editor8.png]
    |  |                          |

2.  keymap editor で 2 で作ったレポジトリを選択して各種設置をカスタマイズして Save します
    - カスタマイズの方法などはネットで調べてください。https://sensai-gadget.com/keymap-editor-usage/ などは情報が多そうです。

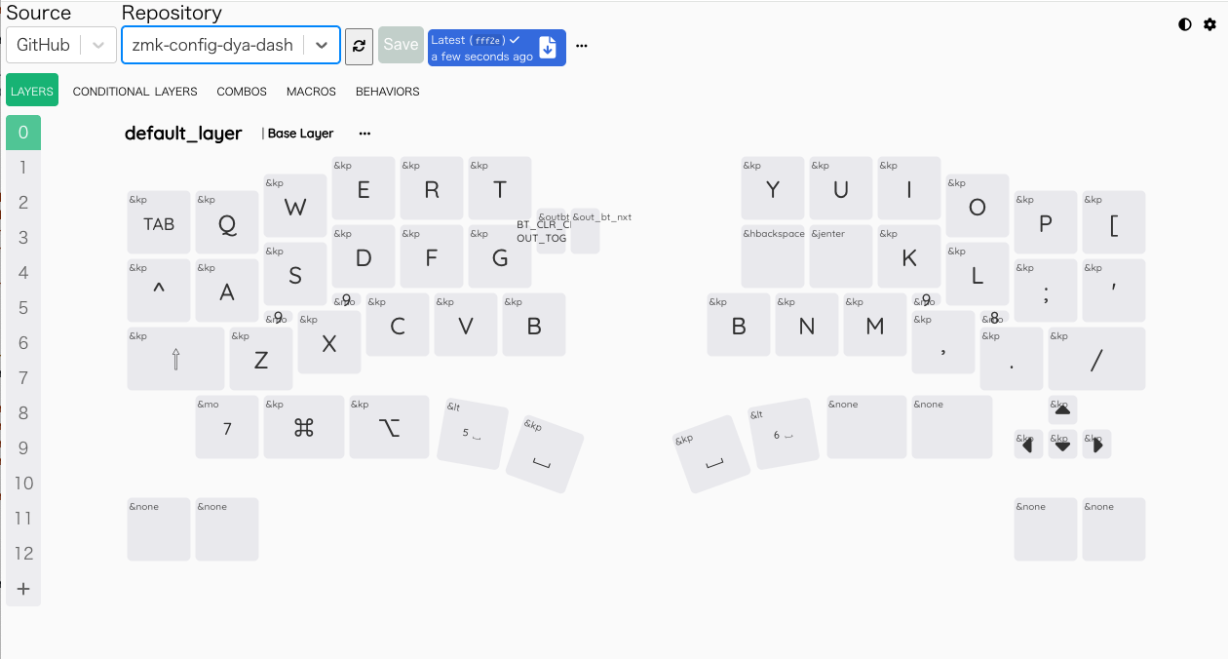
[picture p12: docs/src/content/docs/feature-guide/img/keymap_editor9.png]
    

3.  github のレポジトリに戻ると新しい変更が増えていてファームウェアのビルドが始まっています
4.  ビルドが完了したら Actions の Summary からファームウェアの zip をダウンロードして、キーボードにファームウェアを書き込みます。

## 3. プログラミングによるカスタマイズ

keymap editor を使ったカスタマイズの "設定レポジトリを Github に準備する" に従ってレポジトリ作ります。
あとはレポジトリの readme などを見ながらがんばってください。

main ブランチに push するとビルドが始まるほか、ビルドツールをインストールすればローカルでビルドもできるようになっています。

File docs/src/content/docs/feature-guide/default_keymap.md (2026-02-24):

---
title: デフォルトキーマップ
description: DYA2 のデフォルトキーマップの解説
sidebar:
  order: 1
---

最新のキーマップは [Github の自動生成画像](https://github.com/cormoran/zmk-keyboard-dya2?tab=readme-ov-file#default-keymap) か DYA Studio の UI をご覧ください。

主要なレイヤーのデフォルトのキーマップについて解説します。
すべての割り当ては DYA Studio から編集が可能です。

## Base レイヤー

常にアクティブなレイヤーです。他のレイヤーにキーが設定されていない(`&trans`が設定されている)場合このレイヤーのキーマップが動作します。



#### キーの対応関係

- 縦に分割されている部分は上側がキーを押した時、下がタッチセンサーに触れた時のキーマップです。
- 左右に２つずつある小さなキーは設定キーです。
- 一番下の段の２つのキーは JIS レイアウト時に使うキーで、USレイアウトの場合は使われないので下に表示しています。

## マウスレイヤー

トラックボールを動かすとマウスレイヤーが自動的に有効になります。



#### マウスキー

- `M` キーで左クリック
- `K` キーでミドルクリック
- `L` キーで右クリック
- `,(<)` キーで戻る
- `.(>)` キーで進む

#### タッチセンサーの動作

- 右手小指をずらして `'` でスクロールモード
- `M` に指を置いている間マウスレイヤーモードが維持（されるはずですが少し不安定...）
- 左手の人差し指を右・下にずらして
  - `G` で低速モード
  - `V` で高速モード
- 左手親指部分でもスクロールモード

#### 設定の調整

マウスやスクロールの速度、自動でマウスレイヤーを有効にしない設定など細かな調整は DYA Studio から行えます。

## Config レイヤー

右下から一つ上のキーを押すと Config レイヤーが有効になります。 Config レイヤーは Function キーの他に接続先の設定などのマッピングを設定しています。

- `Q`~`T` BLE, USB 接続先の切り替え
- 左右の `&bootloader` を押すとファームウェア書き込みモードになります。外側のUSBポートでPCと接続した状態で押すことで、 XIAO のリセットボタンをダブルクリックしたのと同じ状態になります。
- 左下の `&studio unlock` は DYA Studio, ZMK Studio に接続した際にキーマップなどのセキュリティが必要な機能を有効化するためのキーです。
  - DYA Studio に無線接続するために、このキーを押すと BLE Advertize が開始されるようにもなっています。



## その他のレイヤー

Win, Mac, iOS, Linux レイヤーは [接続先ごとにキーマップを変える](/dya2-keyboard/feature-guide/default_layer_per_connection) 機能で使用することを想定したレイヤーです。

Scroll レイヤーはトラックボールをスクロール動作にするために使用するレイヤーです。基本的にはマッピングを定義していませんが、スクロール中のみに必要なマッピングを追加することもできます。

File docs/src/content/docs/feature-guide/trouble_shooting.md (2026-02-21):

---
title: トラブルシューティング
description: 想定トラブルとその対応方法を解説します
sidebar:
  order: 100
---

想定されるトラブルやこれまでに問い合わせがあったトラブルへの対応策をまとめたページです。

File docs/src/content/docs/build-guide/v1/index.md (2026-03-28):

---
title: 組み立ての流れ
description: DYA2 v1 の組み立てガイドです
sidebar:
  order: 0
---

このページは [Booth](https://cormoran707.booth.pm/items/7627440) で配布中の DYA2 rev1.1 向けの組み立てガイドです。

DYA2 は基本的にははんだ付けなしで組み立てられるように設計されていますが、一部はんだ付け推奨箇所があります。

組み立ては大きく以下の３つのステップで進めます。

1. **[事前準備](/dya2-keyboard/build-guide/v1/preparation)** - 必要な部品と工具の確認
1. **[ファームウェア](/dya2-keyboard/build-guide/v1/firmware)** - XIAO へのファームウェア書き込み
1. **[組み立て](/dya2-keyboard/build-guide/v1/assembly)** - 基板とケースの組み立て

## 完成イメージ

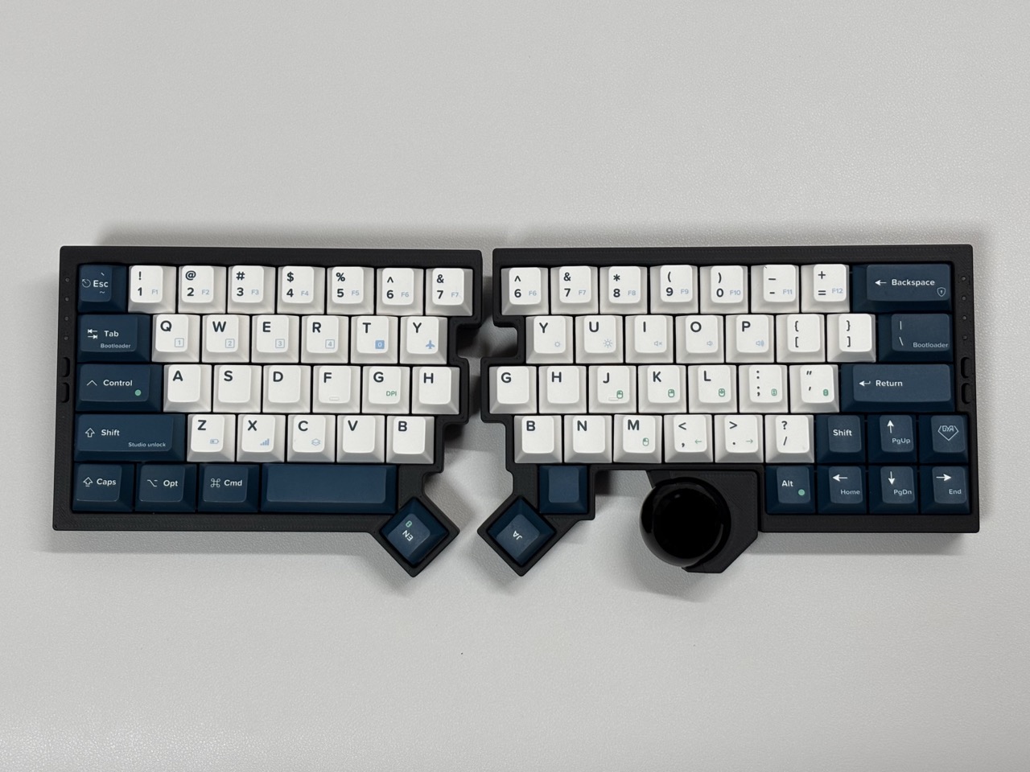
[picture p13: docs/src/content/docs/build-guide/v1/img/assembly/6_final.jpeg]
完成したDYA2キーボード


## 困ったときは

- 部品が不足している場合は、booth のメッセージ機能でお早めにご連絡ください
- 組み立てに失敗した場合や、うまく動かない場合も可能な限りサポートしますのでお気軽にご相談ください
- キーケット等現地販売で購入された場合も booth からメッセージをいただければ対応します

サポートの連絡先：

- [Booth メッセージ](https://cormoran707.booth.pm/items/7627440)
- [GitHub Issues](https://github.com/cormoran/dya2-keyboard/issues)

## 免責事項

- 3Dプリントケースの印刷品質は保証していません。できるだけ綺麗なものを選別していますが、一部荒れた面があったり、バリや傷が残っていることがあります
- タッチセンサー端子の耐久性は保証していません。高頻度にタイピングされる場合はすぐに断線してしまう可能性があります

## 更新履歴

| 日付 | 内容 |
| --- | --- |
| 2026/02/21 | v1.1 向けビルドガイドを公開 |

細かな変更は[github の変更履歴](https://github.com/cormoran/dya2-keyboard/commits/main/)をご覧ください。

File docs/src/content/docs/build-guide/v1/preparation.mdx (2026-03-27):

---
title: 事前準備
description: 必要な部品と工具の確認
sidebar:
  order: 1
---

import { Image } from "astro:assets";
import { Zoom } from "starlight-image-zoom/components";
import Checklist from "../../../../components/Checklist.tsx";
import circuitImage from "./img/preparation_circuit.jpeg";
import circuitImage2 from "./img/preparation_circuit2.jpeg";
import caseImage from "./img/preparation_case.jpeg";
import trackballImage from "./img/preparation_trackball1.jpeg";
import trackballImage2 from "./img/preparation_trackball2.jpeg";
import electricPartsImage from "./img/preparation_electric_parts.jpeg";
import partsImage from "./img/preparation_parts.jpeg";
import screwImage from "./img/preparation_screw.jpeg";

組み立てを始める前に、キットの内容と組み立てに必要な部品、工具を確認します。

## キット同梱部品の確認

3D プリント製パーツは非常に小さく種類もたくさんあります。
組み立て前に全てのパーツが入っているか確認お願いします。

パーツが足りない場合は購入したプラットフォームのメッセージ機能でお早めにご連絡ください。

| カテゴリ | 内容物 |
| --- | --- |
| 回路基板 | <ul><li>基板（厚み 1.6mm、トラックボールセンサー取り付け済み）</li><li>トッププレート（FR4）</li></ul> <div className="image-row"><Zoom label="回路基板パック（裏面）"><Image src={circuitImage} alt="回路基板パック（裏面）"  /></Zoom><Zoom label="回路基板パック（表面）"><Image src={circuitImage2} alt="回路基板パック（表面）" /></Zoom></div> |
| ケース | <ul><li>トップケース 左右</li><li>ボトムケース 左右</li><li>ボトムエンブレム x2</li><li>組み立て済み単４電池ケース x2</li></ul> <div className="image-row"><Zoom label="ケースパック"><Image src={caseImage} alt="ケースパック" /></Zoom></div> |
| トラックボールホルダー | <ul><li>トラックボールケース</li><li>セラミックボール x3（取り付け済み）</li><li>センサー固定パーツ</li></ul> <div className="image-row"><Zoom label="トラックボールケース（上面）"><Image src={trackballImage} alt="トラックボールケース（上面）"  /></Zoom><Zoom label="トラックボールケース（側面）"><Image src={trackballImage2} alt="トラックボールケース（側面）"  /></Zoom></div> |
| 電子部品パック | <ul><li>制御基板 x2（２つつながった状態）</li><li>13pin 1.27mm ピッチコンスルー x4（制御基板に取り付け済み）</li><li>タクトスイッチ x4</li><li>TadPole ピン x8</li><li>トラックボールセンサー用レンズ x1</li><li>タッチセンサー端子 x8</li><li>6pin FFC ケーブル x1</li><li>24pin FFC ケーブル x2</li></ul> <div className="image-row"><Zoom label="電子部品パック"><Image src={electricPartsImage} alt="電子部品パック"  /></Zoom></div> |
| 3Dプリント部品パック | <ul><li>電池カバー x2</li><li>XIAO 固定用カバー x2</li><li>設定スイッチボタン x4</li><li>電源スイッチカバー x2</li><li>リセットボタン x1（右側用）</li></ul> <div className="image-row"><Zoom label="部品パック"><Image src={partsImage} alt="部品パック"  /></Zoom></div> |
| ネジパック | 以下の3つに分けてパッキングされています。A、B、C の刻印がない場合は画像から判断してください。<ul><li>**A**: ボトムケース内部用<ul><li>電池ケース取り付け用 M2 5mm x4</li><li>制御基板取り付け用 M2 5mm x4、M2 8mm x6</li><li>ナイロンワッシャー x3</li></ul></li><li>**B**: ケース上下固定用<ul><li>上辺固定用 M2 5mm x4</li><li>下辺固定用 M2 8mm x5</li><li>ボトムエンブレム取り付け用 M2 4mm x4（黒色）</li><li>トラックボール取り付け用 M2 4mm x3（黒色）</li></ul></li><li>**C**: タッチセンサー固定用 M2 3mm x8</li></ul> <div className="image-row"><Zoom label="ネジパック"><Image src={screwImage} alt="ネジパック"  /></Zoom></div> |
| その他 | <ul><li>ゴム足 x8</li></ul> |
| おまけ | 在庫状況によって入っていたり入っていなかったりします。入っていなかったらごめんなさい。<ul><li>予備部品 適量</li><li>おすすめのキースイッチ x2〜4<ul><li>マウスの右クリックにおすすめのタクタイルスピードスイッチ</li><li>音が良い気がするリニアスイッチ</li></ul></li></ul> |

## 別途購入が必要な部品

キット以外に、以下の部品をご自身で準備していただく必要があります。

- XIAO nRF52840 Plus
  - 姉妹品の XIAO nRF52840（Plus なし）は**使用できません**
  - [TALPKEYBOARD](https://shop.talpkeyboard.com/products/seeed-studio-xiao-nrf52840-xiao-ble) や[勇者工房](https://shop.yushakobo.jp/products/10946)などで購入できます
- Cherry MX 互換キースイッチ × 72個
  - Kailh Choc low-profile スイッチは**使用できません**
  - 左クリック割り当ての M キーにはタクタイルスピードスイッチがおすすめです
- キーキャップ（一式）
  - 6, 7, Y, G, H, B に相当するキーが左右両方にあります
  - [YUZU keycaps](https://yuzukeycaps.com/c/333f67eb-9f7d-4774-9740-c19d98eecc7f) でオリジナルデザインを公開しています。必要なキーキャップの確認にもご利用ください。
  - 英語配列 R4：左 1.25u×3、2.75U×1、1U×1　右 1U×2、トラックボール、1U×4
  - 日本語配列 R4：左 1.25u×4、1.5U×1、1U×1　右 1U×2、トラックボール、1U×4
  - R3 右端の Shift キーが 1U サイズになっています
- スタビライザー 2U x 4 (JIS の場合3つ)
  - ネジ固定タイプのスタビライザーはネジがキーソケットと干渉する可能性があります。
  - 作者は[遊舎工房のスタビライザー](https://shop.yushakobo.jp/products/a0500st?variant=37665699463329)を使用しています
- 34mm トラックボール用ボール × 1
  - ペリックスの黒玉推奨です
  - ボールの色によって安定性が異なる可能性があります
  - ペリックスの黒玉、ERGO M575 付属の青では快適に動作することを確認しています
  - シルバー(メーカー不明)は動作が不安定でした
  - サンワサプライの黒玉は全く動きませんでした
  - ペリックスの白玉は全く動きませんでした
- 両面テープ
  - タッチセンサーの固定に使用します
- 単４電池 × 2
  - デフォルトのファームウェアはニッケル水素電池の電圧特性を想定した残量計算になっています
- USB ケーブル × 2
  - PC 接続用：片側が Type-C のケーブル（USB 2.0 以上、データ通信対応）
  - 左右接続用：Type-C to Type-C ケーブル（USB 2.0 以上、データ通信対応）

## 必要な工具

- ニッパー、ペンチ
  - 基板の切り離しに使用します
- プラスドライバー（0番と1番サイズ）
- はんだごて（オプション）
  - 必須ではありませんが、いくつかはんだ付け推奨箇所があります
  - また、基板はんだ付け済みの状態でお届けしますが、万が一はんだが外れている場合は、可能な範囲で購入者の方で追加のはんだ付けをしていただけると助かります。
- ピンセット（オプション）
  - 小さな部品の取り扱いに便利です

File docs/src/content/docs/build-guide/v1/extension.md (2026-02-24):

---
title: 追加のカスタマイズ
description: DYA2のカスタマイズオプション
sidebar:
  order: 4
---

DYA2 にはいくつかのカスタマイズオプションがあります。

## 真鍮製エンブレムプレート

ボトムケースのエンブレムプレートを 3D プリント製から真鍮製に変更できます。真鍮プレートにすることで重量が増し、タイピング時の安定性が向上します。

真鍮プレートはご自身で [JLCCNC](https://jlccnc.com/) 等のCNC加工サービスに発注していただく形になります。データは [GitHub リポジトリ](https://github.com/cormoran/dya2-keyboard/tree/main/hardware/dya-v2-case) で公開している "For CNC" の step ファイルをご利用いただけます。
以下は JLCCNC での発注例です。

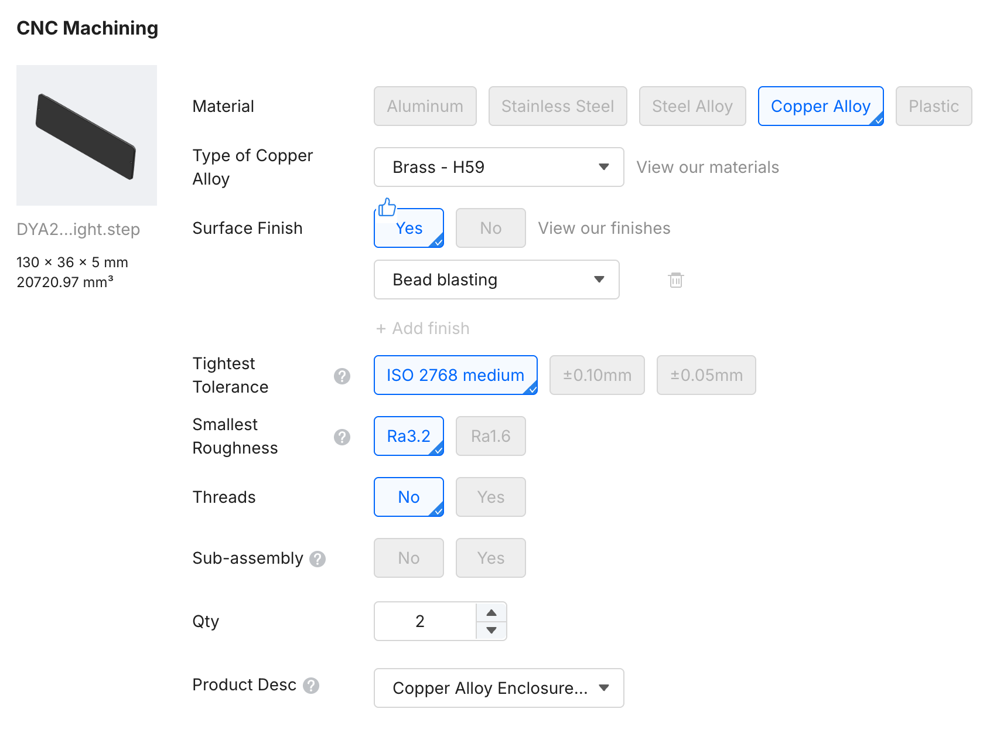
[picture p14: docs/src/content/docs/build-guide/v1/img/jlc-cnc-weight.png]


:::note
非常におすすめしたいカスタマイズのため、今後ご自身で発注いただくよりも安価な価格で提供できそうな目処がたった場合は販売する可能性があります。
:::

## Tadpole ピンの硬さ調整

Tadpole ピンには複数の硬さのバリエーションがあります。ご自身で入手することで、スイッチの底打ち感（タイピングの硬さ）を好みに合わせて調整できます。

同梱しているピンクの Tadpole ピンは標準的な硬さのものになります。配布時期や在庫状況によっては別の硬さのものが同梱されている可能性があります。

一部の硬さは [Booth](https://cormoran707.booth.pm) でも販売予定です。

## レジン製ケース

:::note
2026/02/24現在 レジン向けのケースデータはまだ公開していません。公開されているデータはヒートインサートナットを使うことを想定したPLA向けのみになります。
:::

JLC3DPなどにケースデータをご自身で発注することで、透明ケースやスプレーペイントされたケースを作ることができます。

ただし、レジンはねじ穴が弱くなりやすいため、ねじ止め部分に e-サートを取り付けることが推奨されます。ボトムケースに薄い部分があるため e-サートの取り付けは少し難易度が高いです。

## 今後の予定

- **パームレスト**: いい感じのものを作りたい
- **テンティング台**: 少しテンティングするとトラックボールがより使いやすくなりそうです
- **アルミ製トップケース**: 展示用に検討中
- **アルミ製ボトムケース**: 電池カバー部分で CNC 向けの設計変更が必要な状況

github に 2D の DFX ファイルも公開しているので 3D プリンタをお持ちの方はご自分でパームレストやテンティングプレートを設計していただくこともできると思います。
追加で必要な設計データがあれば相談ください。

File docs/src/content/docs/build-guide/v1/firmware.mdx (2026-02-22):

---
title: ファームウェアの書き込み
description: XIAO nRF52840へのファームウェアインストール
sidebar:
  order: 2
---

import { Steps } from "@astrojs/starlight/components";

2 つの XIAO nRF52840 Plus にファームウェアを書き込みます。

## 必要なもの

- XIAO nRF52840 Plus × 2
- USB ケーブル（Type-C、データ通信対応）
- PC

## ファームウェアファイルのダウンロード

ファームウェアレポジトリの [GitHub リリースページ](https://github.com/cormoran/zmk-keyboard-dya2/releases) を開き、最新版の以下のファイルをダウンロードします。

- 右手用: `right_trackball.uf2`
- 左手用: `left.uf2`

## 書き込み手順

### 1 つ目の XIAO（左手用）

<Steps>

1. **XIAO を PC に接続する**

   1 つ目の XIAO nRF52840 Plus を USB ケーブルで PC と接続します。

2. **書き込みモードに入る**

   XIAO のリセットボタンを素早く **2 回** 押します。
   PC に「XIAO-SENSE」という名前の USB ドライブが表示されれば成功です。
   詳しくは[こちらのサイト](https://qiita.com/KentaHarada/items/3e1612116ec45462a837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)などを参照してください。

3. **ファームウェアをコピーする**

   {/* ダウンロードした左手用のファームウェア（`left.uf2`）を「XIAO-SENSE」ドライブにドラッグ＆ドロップします。 */}

4. **書き込み完了を確認する**

   コピーが完了すると「XIAO-SENSE」ドライブが自動で切断されます。

</Steps>

### 2 つ目の XIAO（右手用）

<Steps>

1. **XIAO を PC に接続する**

   2 つ目の XIAO nRF52840 Plus を USB ケーブルで PC と接続します。

2. **書き込みモードに入る**

   同様にリセットボタンを素早く **2 回** 押します。

3. **ファームウェアをコピーする**

   右手用のファームウェア（`right_trackball.uf2`）を「XIAO-SENSE」ドライブにドラッグ＆ドロップします。

4. **書き込み完了を確認する**

   コピーが完了すると「XIAO-SENSE」ドライブが自動で切断されます。

</Steps>

どちらの XIAO に左右どちらのファームウェアを書き込んだか覚えておいてください。

:::note
左右を逆に取り付けても回路は壊れませんが、キーが逆転したりトラックボールが動かなかったりします。もし左右がわからなくなった場合でも、組み立て後に再度正しいファームウェアを書き込むことができます。
:::

## トラブルシューティング

**「XIAO-SENSE」ドライブが表示されない場合**

- USB ケーブルがデータ通信対応であることを確認してください（充電専用ケーブルは不可）
- リセットボタンを押す速さが遅い場合は表示されないことがあります。素早く 2 回押してください

**ファームウェアのコピー後に動作しない場合**

- 左右のファームウェアが逆になっていないか確認してください
- 再度書き込みモードに入り、正しいファームウェアを書き込み直してください

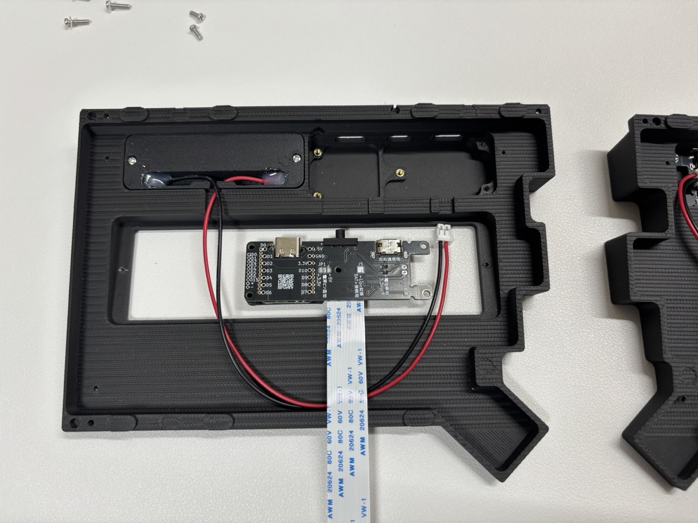
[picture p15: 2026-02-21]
docs/src/content/docs/build-guide/v1/img/assembly/2_2_6_mount_left.jpeg

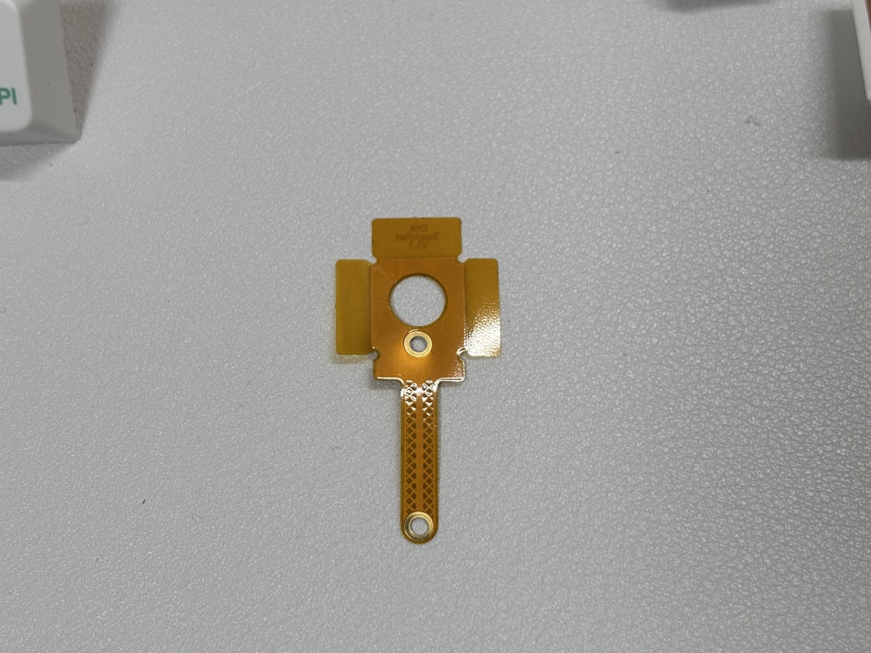
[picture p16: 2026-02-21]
docs/src/content/docs/build-guide/v1/img/assembly/5_5_touch_sensor2.jpeg

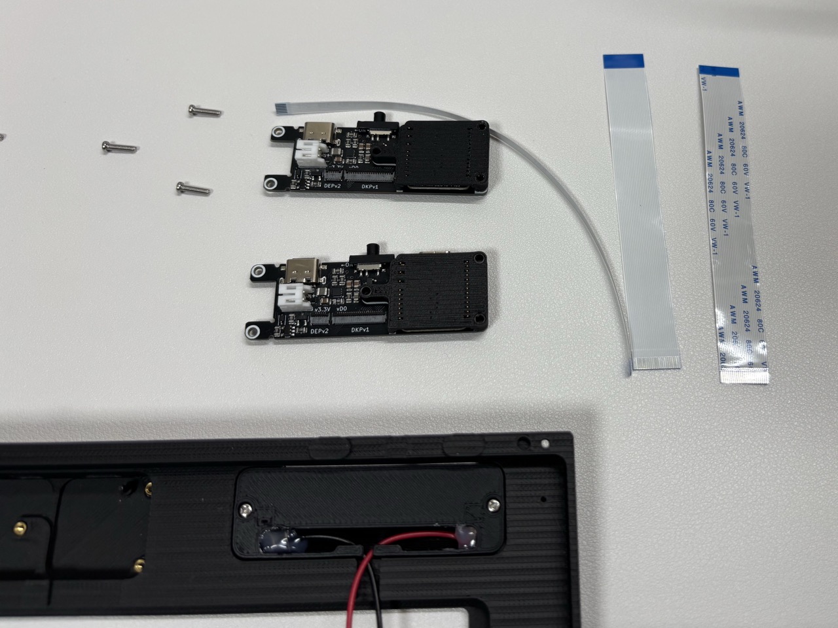
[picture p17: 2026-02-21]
docs/src/content/docs/build-guide/v1/img/assembly/2_2_3_ffc_cables.jpeg

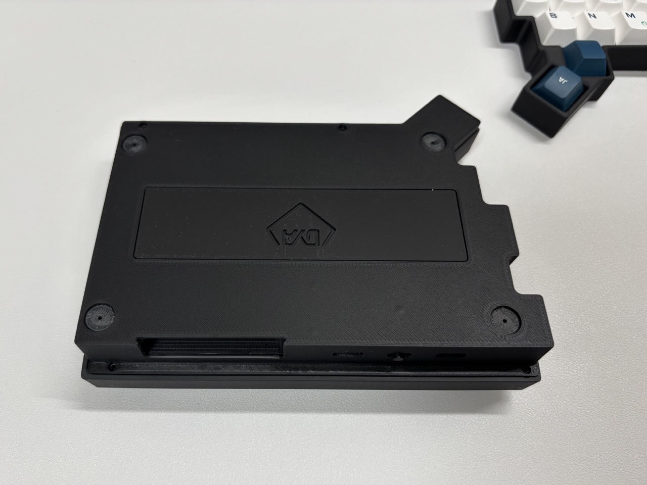
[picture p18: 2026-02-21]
docs/src/content/docs/build-guide/v1/img/assembly/6_1_left_merge.jpeg

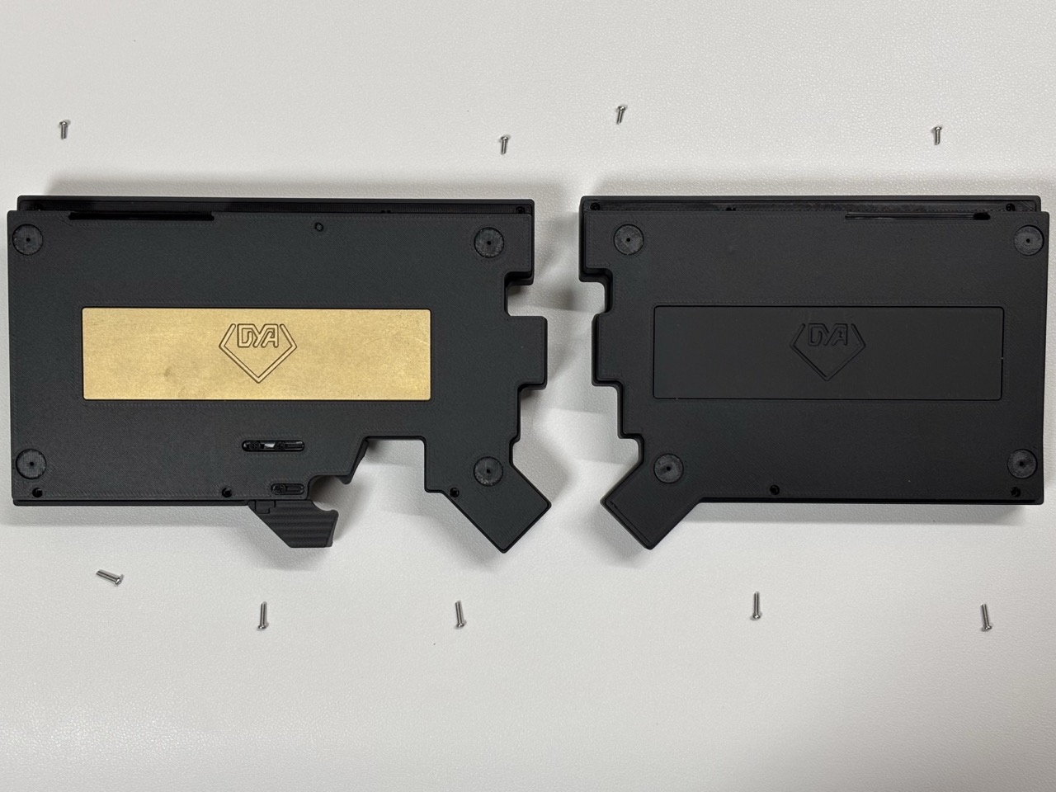
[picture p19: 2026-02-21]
docs/src/content/docs/build-guide/v1/img/assembly/6_3_screw.jpeg

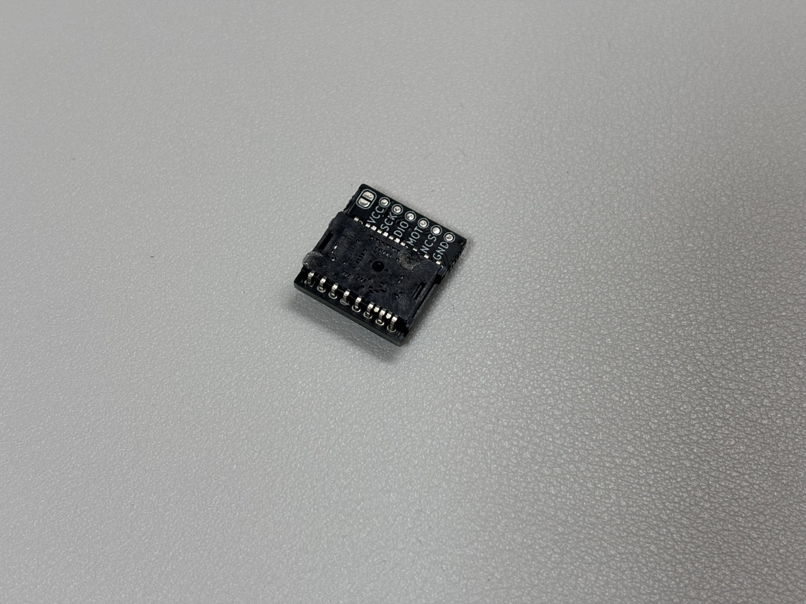
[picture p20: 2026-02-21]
docs/src/content/docs/build-guide/v1/img/assembly/4_trackball_lens2.jpeg

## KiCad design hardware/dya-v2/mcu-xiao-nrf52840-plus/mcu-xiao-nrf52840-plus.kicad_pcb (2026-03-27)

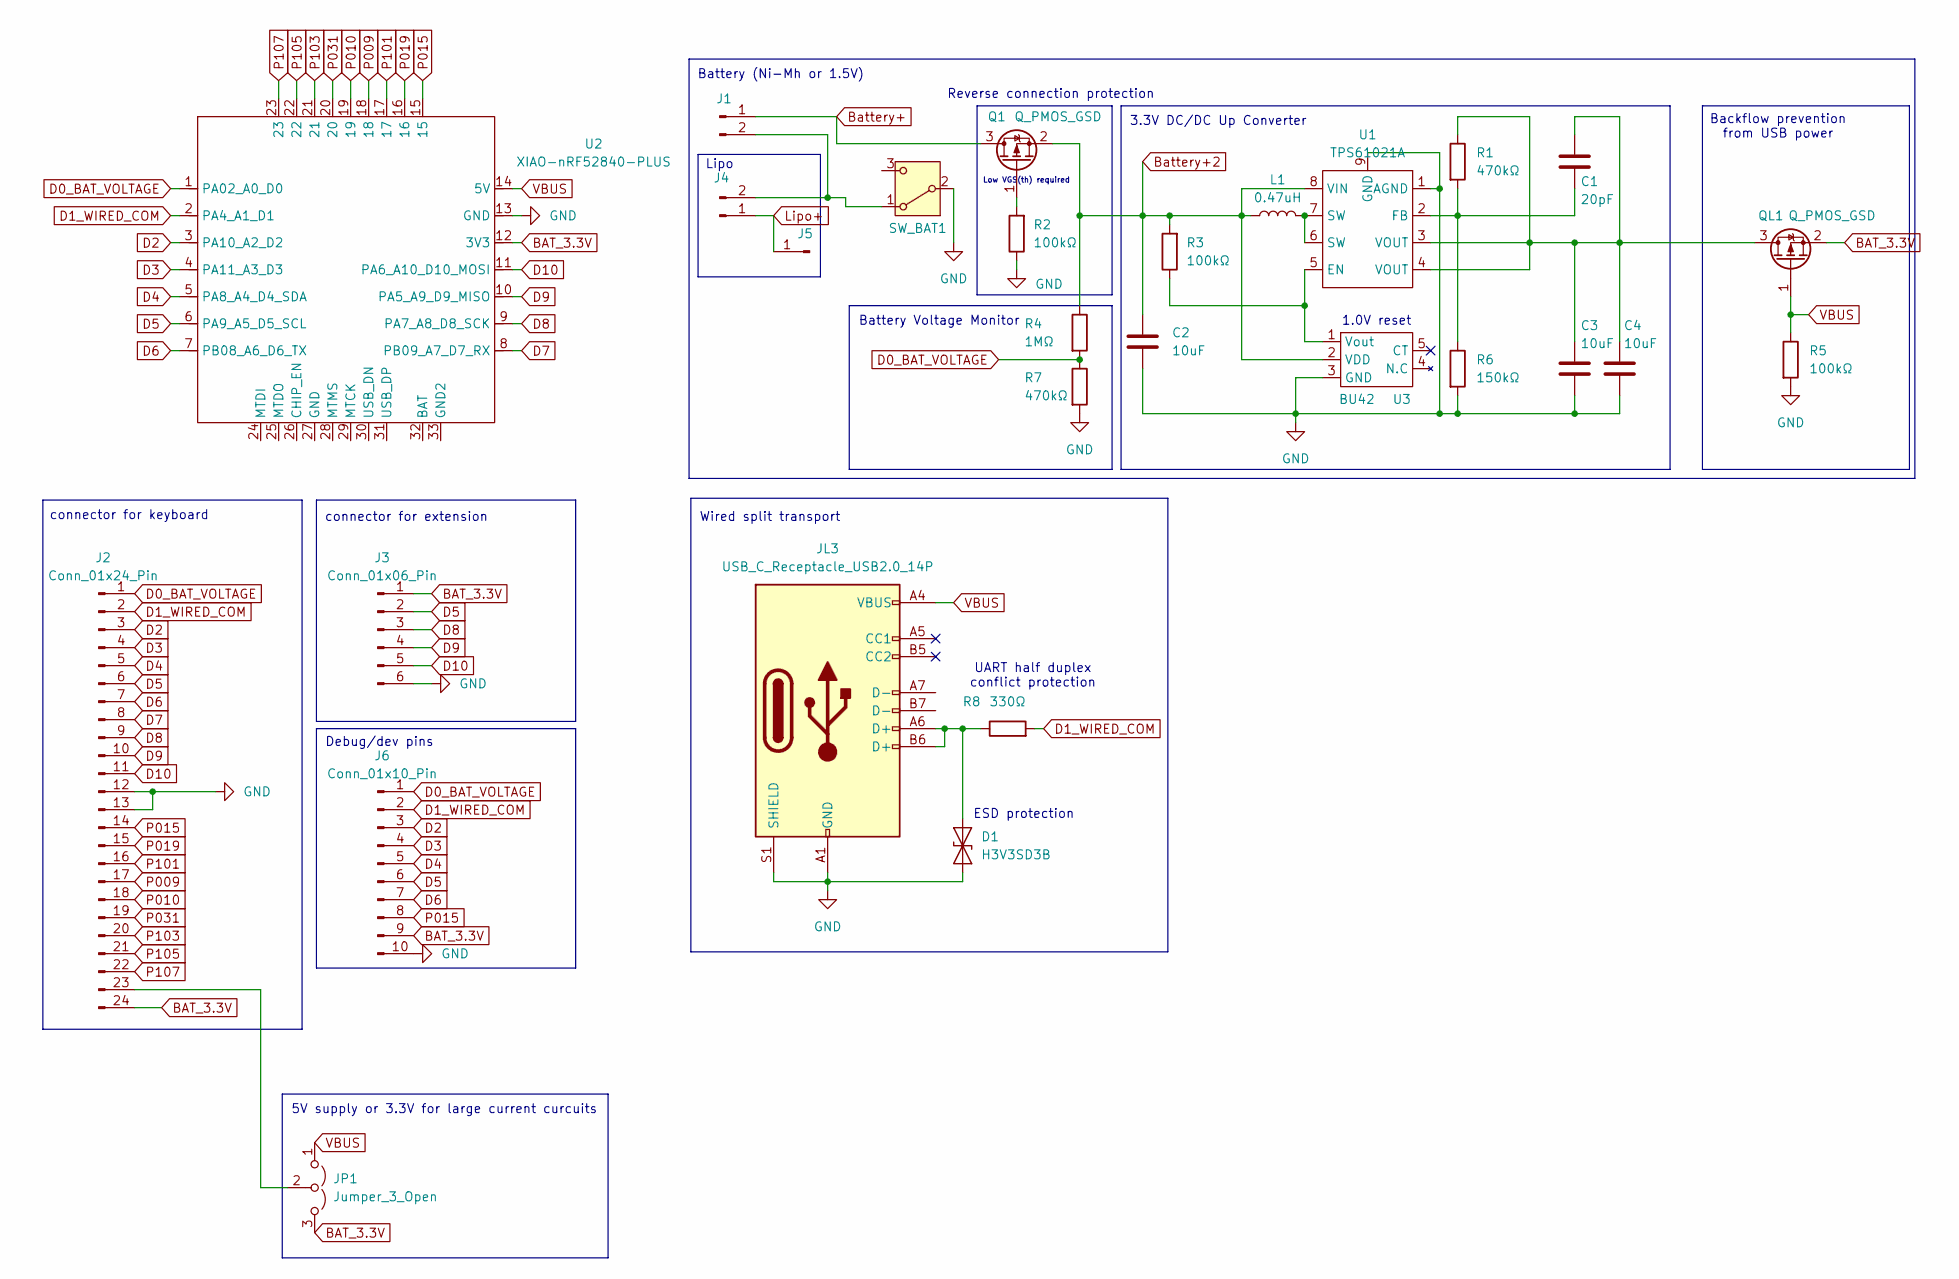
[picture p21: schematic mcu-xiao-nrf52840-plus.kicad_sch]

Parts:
C1: 20pF; C_0805_2012Metric; LCSC C1798
C2, C3, C4: 10uF; C_0805_2012Metric; LCSC C15850
D1: H3V3SD3B; D_SOD-323; LCSC C20615802
J1: Conn_01x02_Pin; JST_PH_S2B-PH-K_1x02_P2.00mm_Horizontal; LCSC C173752
J2: Conn_01x24_Pin; HIROSE-FH34SRJ-24S-0.5SH; LCSC C324726
J3: Conn_01x06_Pin; JUSHUO-AFH34-S06FIA-1H; LCSC C224194
J4: Conn_01x02_Pin; JST_PH_S2B-PH-K_1x02_P2.00mm_Horizontal
J5: Conn_01x01_Pin; SolderWire-0.25sqmm_1x01_D0.65mm_OD1.7mm
J6: Conn_01x10_Pin; PinHeader_1x10_P1.27mm_Vertical
JL3: USB_C_Receptacle_USB2.0_14P; USB_C_ Recessed_ YTC-TC16-31_1.2mm; LCSC C2927296
JP1: Jumper_3_Open; SolderJumper-3_P1.3mm_Open_RoundedPad1.0x1.5mm
L1: 0.47uH; L_1008_2520Metric; LCSC C703140
Q1: Q_PMOS_GSD; SOT-23; LCSC C144153
QL1: Q_PMOS_GSD; SOT-23; LCSC C15127
R1, R7: 470kΩ; R_0805_2012Metric; LCSC C17709
R2, R3, R5: 100kΩ; R_0805_2012Metric; LCSC C149504
R4: 1MΩ; R_0805_2012Metric; LCSC C17514
R6: 150kΩ; R_0805_2012Metric; LCSC C17470
R8: 330Ω; R_0805_2012Metric; LCSC C17630
SW_BAT1: SW_SPDT; SSSS811101; LCSC C109335
U1: TPS61021A; WSON-8-1EP_2x2mm_P0.5mm_EP0.9x1.6mm; LCSC C193037
U2: XIAO-nRF52840-PLUS; XIAO_nRF52840_plus_hybrid
U3: BU42; BU42XX; LCSC C2066584

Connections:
BAT_3.3V: J2.24, J3.1, J6.9, JP1.3 (B), QL1.2 (S), U2.12 (3V3)
Battery+: J1.1, Q1.3 (D)
Battery+2: C2.1, L1.1, Q1.2 (S), R3.2, R4.1, U1.8 (VIN), U3.2 (VDD)
D0_BAT_VOLTAGE: J2.1, J6.1, R4.2, R7.1, U2.1 (PA02_A0_D0)
D1_WIRED_COM: J2.2, J6.2, R8.2, U2.2 (PA4_A1_D1)
D2: J2.3, J6.3, U2.3 (PA10_A2_D2)
D3: J2.4, J6.4, U2.4 (PA11_A3_D3)
D4: J2.5, J6.5, U2.5 (PA8_A4_D4_SDA)
D5: J2.6, J3.2, J6.6, U2.6 (PA9_A5_D5_SCL)
D6: J2.7, J6.7, U2.7 (PB08_A6_D6_TX)
D7: J2.8, U2.8 (PB09_A7_D7_RX)
D8: J2.9, J3.3, U2.9 (PA7_A8_D8_SCK)
D9: J2.10, J3.4, U2.10 (PA5_A9_D9_MISO)
D10: J2.11, J3.5, U2.11 (PA6_A10_D10_MOSI)
GND: C2.2, C3.2, C4.2, D1.2 (A2), J2.12, J2.13, J3.6, J6.10, JL3.A1 (GND), JL3.A12 (GND), JL3.B1 (GND), JL3.B12 (GND), JL3.S1 (SHIELD), R2.1, R5.2, R6.2, R7.2, SW_BAT1.2 (B), U1.1 (AGND), U1.9 (GND), U2.13 (GND), U3.3 (GND)
Lipo+: J4.1, J5.1
unnamed: D1.1 (A1), JL3.A6 (D+), JL3.B6 (D+), R8.1
unnamed: J1.2, J4.2, SW_BAT1.1 (A)
unnamed: J2.23, JP1.2 (C)
unnamed: L1.2, U1.6 (SW), U1.7 (SW)
unnamed: Q1.1 (G), R2.2
unnamed: C1.1, C3.1, C4.1, QL1.3 (D), R1.1, U1.3 (VOUT), U1.4 (VOUT)
unnamed: R3.1, U1.5 (EN), U3.1 (Vout)
unnamed: C1.2, R1.2, R6.1, U1.2 (FB)
P009: J2.17, U2.18
P010: J2.18, U2.19
P015: J2.14, J6.8, U2.15
P019: J2.15, U2.16
P031: J2.19, U2.20
P101: J2.16, U2.17
P103: J2.20, U2.21
P105: J2.21, U2.22
P107: J2.22, U2.23
VBUS: JL3.A4 (VBUS), JL3.A9 (VBUS), JL3.B4 (VBUS), JL3.B9 (VBUS), JP1.1 (A), QL1.1 (G), R5.1, U2.14 (5V)

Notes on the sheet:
connector for keyboard
1.0V reset
ESD protection
3.3V DC/DC Up Converter
Battery (Ni-Mh or 1.5V)
Reverse connection protection
Backflow prevention from USB power
Battery Voltage Monitor
Wired split transport
5V supply or 3.3V for large current curcuits
Debug/dev pins
Lipo
Low VGS(th) required
connector for extension
UART half duplex conflict protection

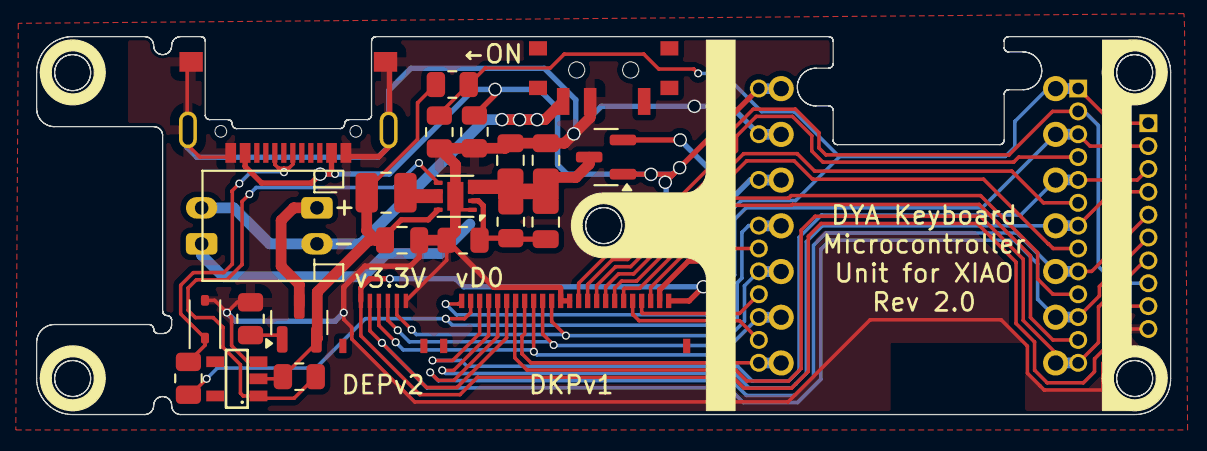
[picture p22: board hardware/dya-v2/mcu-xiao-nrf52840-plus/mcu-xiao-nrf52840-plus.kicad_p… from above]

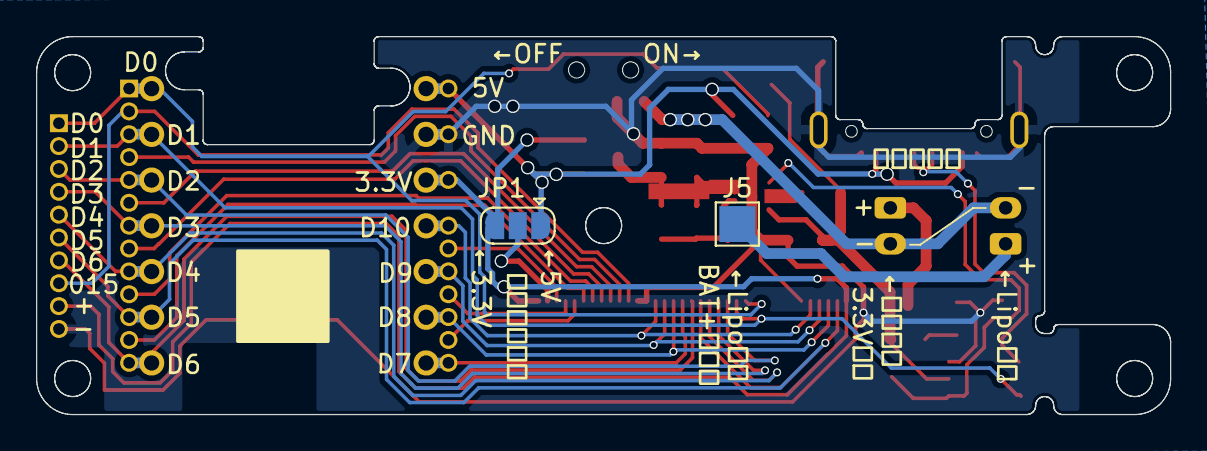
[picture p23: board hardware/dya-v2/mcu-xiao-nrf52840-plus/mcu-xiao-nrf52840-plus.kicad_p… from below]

Board: 2 copper layers, 63.0 x 21.0 mm, 28 parts (3 on the bottom side), 34 nets.

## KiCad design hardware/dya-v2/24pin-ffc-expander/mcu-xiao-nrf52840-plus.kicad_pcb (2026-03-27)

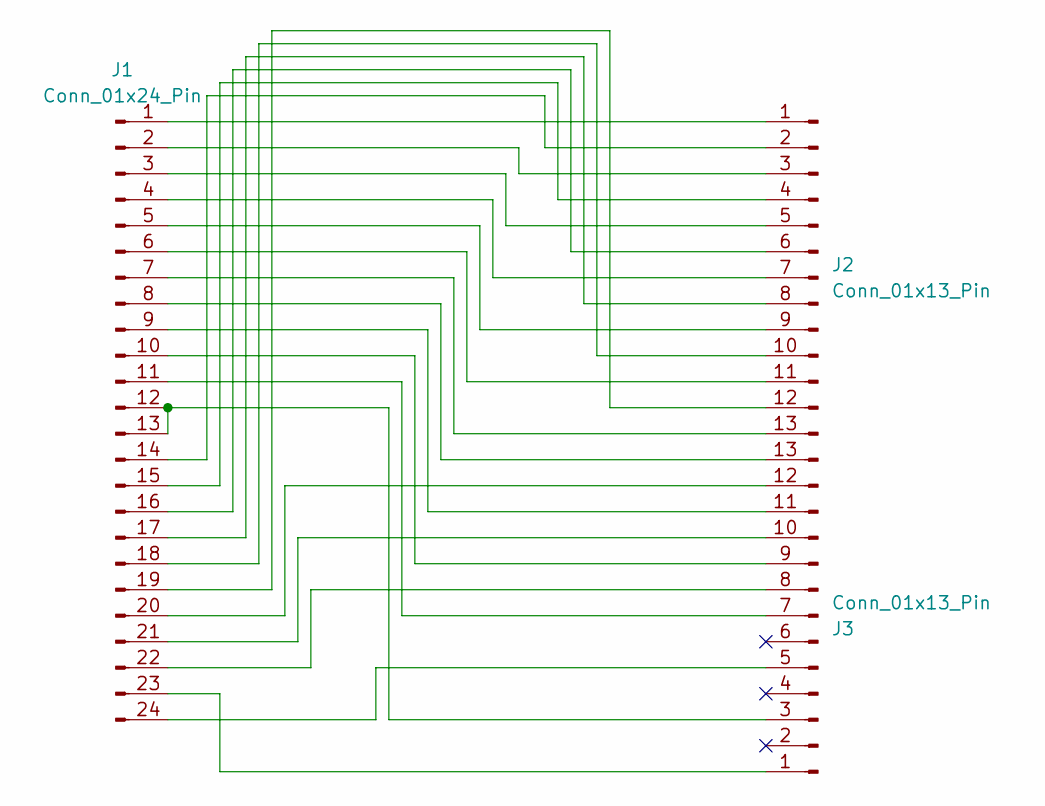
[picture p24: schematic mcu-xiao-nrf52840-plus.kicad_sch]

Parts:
J1: Conn_01x24_Pin; HIROSE-FH34SRJ-24S-0.5SH; LCSC C324726
J2, J3: Conn_01x13_Pin; PinHeader_1x13_P1.27mm_Vertical

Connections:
unnamed: J1.1, J2.1
unnamed: J1.2, J2.3
unnamed: J1.3, J2.5
unnamed: J1.4, J2.7
unnamed: J1.5, J2.9
unnamed: J1.6, J2.11
unnamed: J1.7, J2.13
unnamed: J1.8, J3.13
unnamed: J1.9, J3.11
unnamed: J1.10, J3.9
unnamed: J1.11, J3.7
unnamed: J1.12, J1.13, J3.3
unnamed: J1.14, J2.2
unnamed: J1.15, J2.4
unnamed: J1.16, J2.6
unnamed: J1.17, J2.8
unnamed: J1.18, J2.10
unnamed: J1.19, J2.12
unnamed: J1.20, J3.12
unnamed: J1.21, J3.10
unnamed: J1.22, J3.8
unnamed: J1.23, J3.1
unnamed: J1.24, J3.5

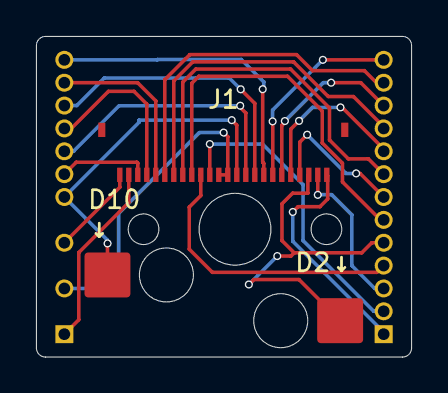
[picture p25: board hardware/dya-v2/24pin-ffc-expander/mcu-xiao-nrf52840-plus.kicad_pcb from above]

Board: 2 copper layers, 20.8 x 17.8 mm, 3 parts (0 on the bottom side), 23 nets.

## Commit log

2026-02-20 Refine build guide document structure and content
    - Add completed keyboard image to overview page
    - Add second circuit board and trackball images side by side in preparation
    - Improve sentence clarity and formatting throughout
    - Fix assembly.mdx heading level bug (## 2.4 → ### 2.4)
    - Fix typo: tadpone → Tadpole
    - Fix contradictory screw size label (M2 9mm was wrongly labeled as 短い方)
    - Fix indentation issues in sections 6.4 and 6.5
    - Remove "(1)" from section 2 title
    - Convert firmware.md to firmware.mdx with Starlight Steps component
    - Add troubleshooting content to firmware page (was TODO)
    - Rewrite extension.md as proper sentences with structure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
2026-02-20 Add React interactivity and visual improvements to build guide
    - Add Checklist.tsx React component with localStorage persistence
    for tracking purchased parts and tools in preparation page
    - Add image-row CSS class for horizontal image layouts
    - Update preparation.mdx to use interactive Checklist for purchase
    list and tools sections; add purchase link row
    - Full rewrite of assembly.mdx with:
    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
2026-02-23 ソケットのはんだ不良関連情報を追加
2026-02-24 Add link to case data
2026-03-05 Add cautions when assembly
2026-03-27 Add ffc expander and xiao expander circuit
    [mcu-xiao-nrf52840-plus.kicad_pcb, mcu-xiao-nrf52840-plus.kicad_sch, mcu-xiao-nrf52840-plus.step]
2026-03-27 Update docs related to XIAO reset switch
2026-10-12 docs: add 25mm trackball build guide
